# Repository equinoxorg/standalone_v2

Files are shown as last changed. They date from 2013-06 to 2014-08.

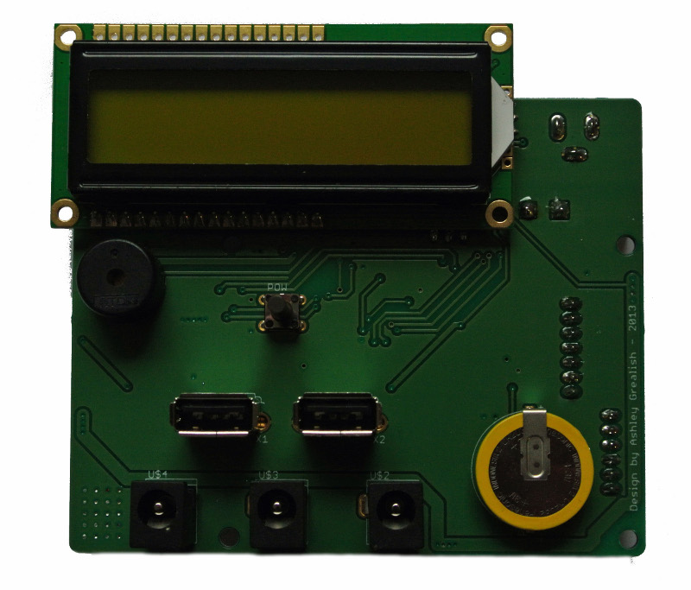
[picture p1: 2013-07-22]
Media/img_front.jpg

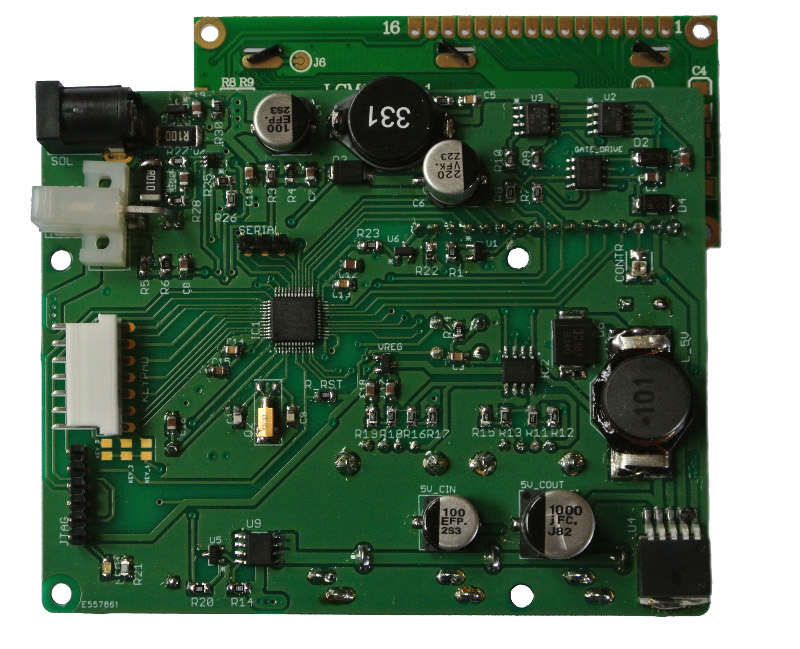
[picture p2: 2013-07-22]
Media/img_back.jpg

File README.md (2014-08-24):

#Standalone 2013 Designs

##Contents

* Hardware: The PCB designs for Pro and Home units
* Software: The source code of the embedded software
* Mechanical: The designs for the faceplate and physical casing
* Media: Any images or other media

Prototype Front

Prototype Back

##Hardware
This project includes hardware schematics and board layouts for Version 2 of the Standalone Battery Box (izuba.box) for e.quinox (www.e.quinox.org).

Cadsoft EAGLE v6 was the tool of choice when designing PCBs.

##Software

This project includes the ARM-based microcontroller software for Version 2 of the Standalone Battery Box (izuba.box) for e.quinox (www.e.quinox.org).

The project uses the Lite version of the Keil µVision IDE.

###Notes
Some code has been deliberately excluded as it would allow misuse of the payment system. If this is a problem please contact [info@e.quinox.org](mailto:info@e.quinox.org).

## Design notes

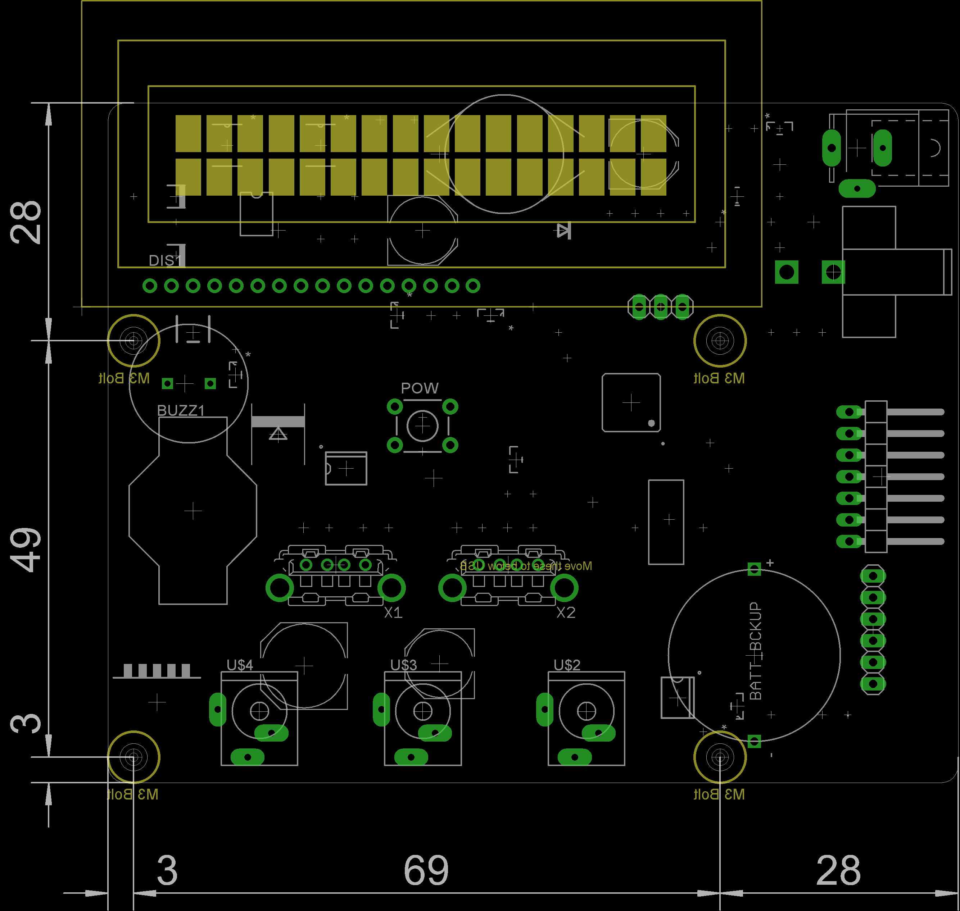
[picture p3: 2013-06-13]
Hardware/standalone/dimensions.png

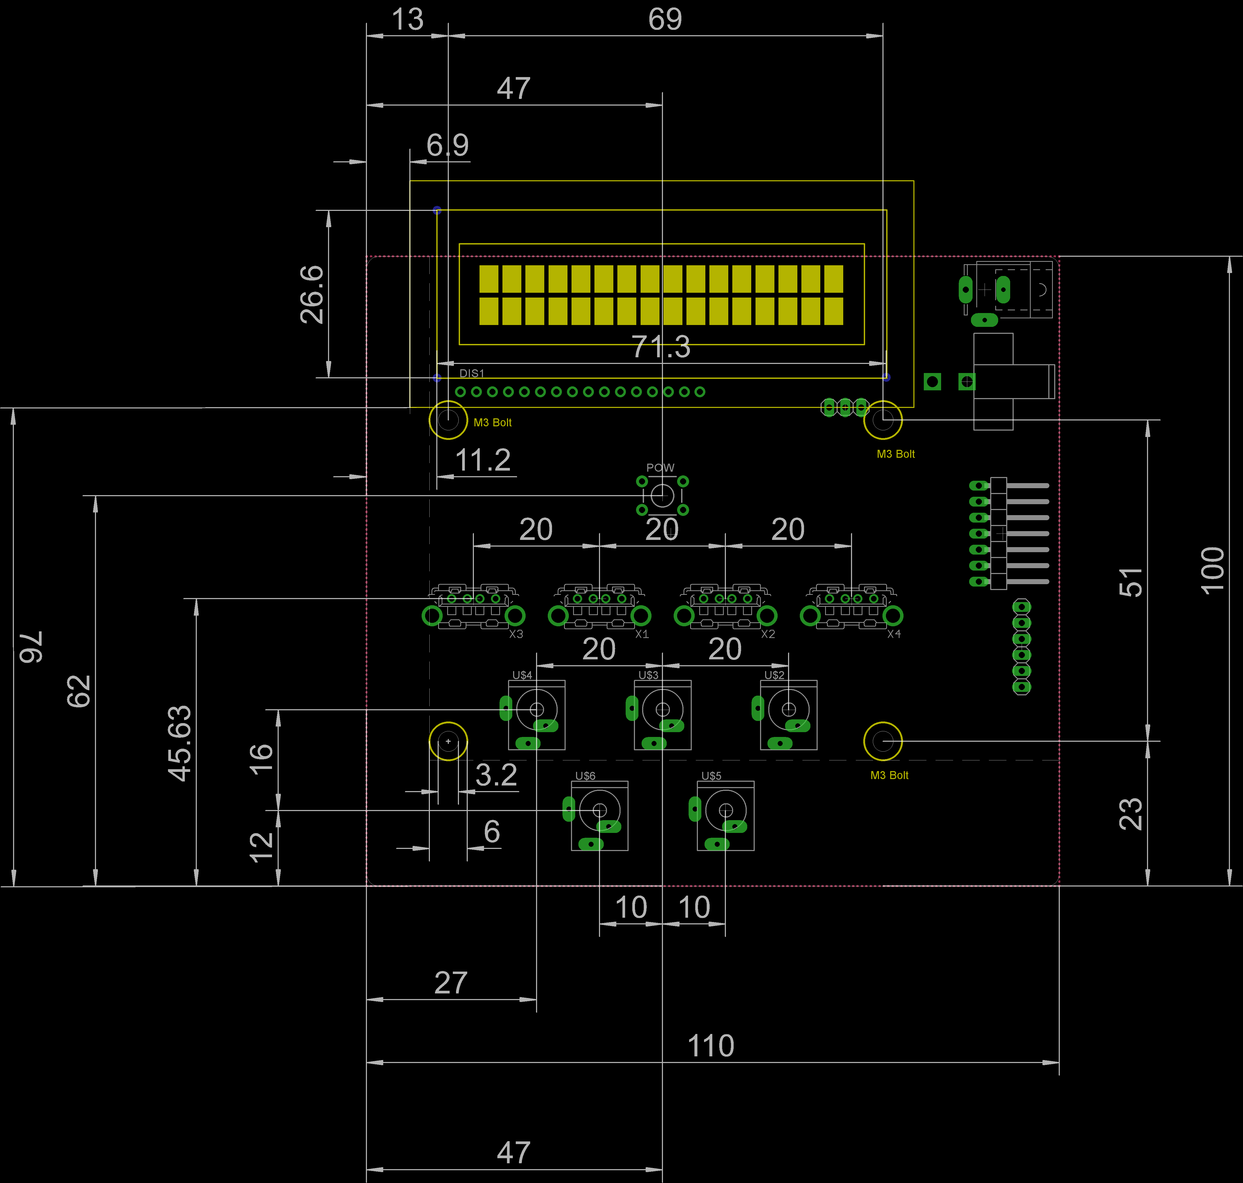
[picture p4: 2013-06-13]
Hardware/standalone_pro/Dimensions.png

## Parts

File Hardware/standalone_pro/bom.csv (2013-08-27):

Qty | Value | Device | Package | Parts | Description | FARNELL | MF | MPN | OC_FARNELL | OC_MOUSER | OC_NEWARK | PACKAGE | RS | SUPPLIER | TOBY
1 |  | BC847B-NPN-SOT23-BEC | SOT23-BEC | T1 | NPN Transistror
1 |  | JACK-PLUG0 | SPC4077 | SOL | DC POWER JACK |  |  |  | unknown |  | unknown |  |  |  | DC-001-A-2.1mm-R
1 |  | PINHD-1X3 | 1X03 | SERIAL | PIN HEADER
1 |  | PINHD-1X6 | 1X06 | JTAG | PIN HEADER
1 |  | PINHD-1X7/90 | 1X07/90 | KEYPAD | PIN HEADER |  |  |  | 588763
1 |  | TAC_SWITCHPTH | TACTILE-PTH | POW | Momentary Switch |  |  |  |  |  |  |  | 758-1979
1 | 0.01 | R-EU_R2512 | R2512 | RS_B | RESISTOR, European symbol
1 | 0.1 | R-EU_R2512 | R2512 | RS_S | RESISTOR, European symbol
1 | 0R | R-EU_M0805 | M0805 | R19 | RESISTOR, European symbol
2 | 1.33k | R-EU_M0805 | M0805 | R5, R14 | RESISTOR, European symbol
2 | 10 | R-EU_M0805 | M0805 | R17, R18 | RESISTOR, European symbol
1 | 100 | R-EU_M0805 | M0805 | R12 | RESISTOR, European symbol
1 | 1000uF | CPOL-EUG | PANASONIC_G | C22 | POLARIZED CAPACITOR, European symbol |  |  |  | 1244342
1 | 100K | R-EU_M0805 | M0805 | R_RST | RESISTOR, European symbol
5 | 100nF | C-EUC0805K | C0805K | C2, C11, C15, C16, C18 | CAPACITOR, European symbol
2 | 100uF | CPOL-EUE | PANASONIC_E | C8, C19 | POLARIZED CAPACITOR, European symbol |  |  |  | 1539489
1 | 100uH | INDUC_BOURNES_SDR2207 | INDUC_BOURNS_SDR2207 | L_5V |  | 1612709 |  |  | 1612709
4 | 10K | R-EU_M0805 | M0805 | R4, R13, R15, R16 | RESISTOR, European symbol
1 | 10K | R_TRIMM_TC33X | R_TRIMM_RC33X | CONTR |  |  |  |  | 1689863 | 652-TC33X-2-103E
1 | 10M | R-EU_M0805 | M0805 | R3 | RESISTOR, European symbol
3 | 10uF | C-EUC0805K | C0805K | C3, C13, C17 | CAPACITOR, European symbol
5 | 1k | R-EU_M0805 | M0805 | R2, R10, R20, R21, R22 | RESISTOR, European symbol
1 | 1k65 | R-EU_M0805 | M0805 | R1 | RESISTOR, European symbol
8 | 1uF | C-EUC0805K | C0805K | C1, C4, C5, C9, C10, C14, C20, C21 | CAPACITOR, European symbol
3 | 200 | R-EU_M0805 | M0805 | R6, R7, R11 | RESISTOR, European symbol
1 | 220uF | CPOL-EUF | PANASONIC_F | C12 | POLARIZED CAPACITOR, European symbol |  |  |  | 9695877
1 | 32.768kHz | MC-306 | MC-306 | Q1 | kHz RANGE CRYSTAL UNIT SMD |  |  | MC-306 | 1712823 |  | -
1 | 330u | INDUC_MURATA_1433428C | INDUC_MURATA_1433428C | L_MPPT |  |  |  |  | 1077018
8 | 49.9k | R-EU_M0805 | M0805 | R24, R26, R28, R30, R32, R34, R36, R38 | RESISTOR, European symbol
2 | 5 | R-EU_M0805 | M0805 | R8, R9 | RESISTOR, European symbol
2 | 6.8pF | C-EUC0603K | C0603K | C6, C7 | CAPACITOR, European symbol |  |  |  | 1856141
8 | 75k | R-EU_M0805 | M0805 | R23, R25, R27, R29, R31, R33, R35, R37 | RESISTOR, European symbol
2 | AP1212 | AP1212 | SO8 | IC3, IC4 | Datasheet: http://www.farnell.com/datasheets/608767.pdf |  |  |  | 1825302
1 | B340-13-F | DIODE_B340-13-F | SMC | D6 |  |  |  |  | 1843695
1 | BUZZ_14MM | BUZZ_14MM | BUZZ_14MM_5M_PINS | BUZZ1 |  |  |  |  | 1192513
1 | BZX384-C3V6 | BZX384-C3V6 | SOD323 | D1 |  |  |  |  | 8735654
2 | CON_MOLEX_39_29_1028 | CON_MOLEX_39_29_1028 | MOLEX_39_29_1028 | BATT, INVERTER |  |  |  |  | 1012166
1 | EQUINOX_LOGO_LARGE | EQUINOX_LOGO_LARGE | EQUINOX_LOGO_LARGE | U$1
2 | FDS6690a | DMS3016SSS-13 | SOIC127P600X175-8N | U4, U5 | ENHANCEMENT MODE MOSFET |  |  |  | 9845275 |  |  | SOIC-8
1 | INA213AIDCKT | INA213AIDCKT | SOT65P210X110-6N | U7 | CURRENT SHUNT MONITOR |  |  | INA213AIDCKT | 1754261 |  | 05N1040 | SC-70-6 |  | Texas Instruments
1 | IR2104S | IR2104S | IR2104S | IC1 | Half Bridge Mosfet - IGBT driver SOIC |  |  |  | 8638756
4 | KUSBVX | KUSBVX | KUSBVX | X1, X2, X3, X4 | Vertical,Top Entry Universal Serial Bus Connector KUSBVX Series
5 | KYCON_KLDVX-0202 | KYCON_KLDVX-0202 | KYCON_KLVDX_2020_B | DC1, DC2, DC3, DC4, DC5 |  |  |  |  |  |  |  |  |  |  | DC-031-B
1 | LCD_16X2_R2 | LCD_16X2_R2 | LCD_16X2_R2 | DIS1 | Supplier: info |  |  |  | unknown |  | unknown
1 | LM2576S | LM2576S | TO263-5 | U9 |  |  |  |  | 1469178
1 | MCP1700T-3302E/TT | MCP1700T-3302E/TT | SOT95P237X112-3N | VREG | Low Quiescent Current LDO |  |  | MCP1700T-3302E/TT | 1296592 |  | 88H9817 | SOT23-3 |  | Microchip
4 | NMOS_2N7002 | NMOS_2N7002 | SOT103P240X110-3N | U2, U3, U6, U10 | N-CHANNEL ENHANCEMENT MODE FIELD EFFECT TRANSISTOR |  |  | 2N7002-7-F | 1713823 |  | 25R5679 | SOT-23-3 |  | DIODES INC.
1 | POW_3V3 | LEDCHIPLED_0805 | CHIPLED_0805 | LED1 | LED
1 | RELAY_G5RL-1E | RELAY_G5RL-1E | G5RL-1E | U$2
1 | RENATA_COIN_CELL | PANASONIC_CR2032_1298246 | PANASONIC_CR2032_1298246 | BATT_BCKUP | Farnell Part No: 1298246 |  |  |  | 1298246
1 | S1A-E3/5AT | DIODE-DO-214AC | DO-214AC | D2 | DIODE |  |  |  | 9550216
2 | SSB43L | DIODE_SSB43L | DO214AA | D4, D5 | VISHAY - SSB43L-E3/52T - DIODE, SCHOTTKY, 4A, 30V |  |  |  | 1336556
1 | STM32F050C6T6A | STM32F050C6T6A | LQFP48 | IC2 |  |  |  |  | 2115059
2 | US1D | DIODE-DO-214AC | DO-214AC | D3, D7 | DIODE |  |  |  | 1625280
1 | ZXCT1107SA-7 | ZXCT1107SA-7 | SOT91P240X110-3N | U1 | LOW POWER HIGH-SIDE CURRENT MONITORS |  |  | ZXCT1107SA-7 | 1904027 |  | 55T4047 | SOT-23-3 |  | DIODES INC.

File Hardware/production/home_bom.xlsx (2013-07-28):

e.quinox izuba.box Home Bill Of Materials
Date | 2013-07-17
Qty | Populate | Reference Designator | Pins | SMT? | IC? | SMT Pads | IC Pads | TH Pads | Item Description | Column1 | Column2 | Supplier | Supplier Part No | Manufacturer | Manufacturer Part No | Notes | Unit Price | Order Quantity | Ordered | Total Cost
1 | Y | BATT | 2 | N | N | 0 | 0 | 2 | CON_MOLEX_39_29_1028 | MOLEX_39_29_1028 |  | FARNELL | 1012166 | Molex | 39-29-1028 |  | £0.41 | 83 | 83 | £34.03
1 | Y | BATT_BCKUP | 2 | N | N | 0 | 0 | 2 | RENATA_COIN_CELL | PANASONIC_CR2032_1298246 | Farnell Part No: 1298246 | FARNELL | 1298246 | PANASONIC | CR-2032/HFN |  | £1.02 | 83 | 83 | £84.66
1 | Y | BUZZ1 | 2 | N | N | 0 | 0 | 2 | BUZZ_14MM | BUZZ_14MM_5M_PINS |  | FARNELL | 1192513 | Murata | PKM13EPYH4000-A0 |  | £0.27 | 83 | 83 | £22.41
2 | Y | C1, C9 | 2 | Y | N | 4 | 0 | 0 | 6.8pF | C0603K | CAPACITOR | FARNELL | 1856141 | Multicomp | MCCA000982 |  | £0.02 | 165 | 200 | £3.40
8 | Y | C2, C10, C11, C12, C16, C17, C18, C19 | 2 | Y | N | 16 | 0 | 0 | 1uF | C0805K | CAPACITOR | Quick-Tech | QCC-00106 | Samsung | CL21B105KAFNNNE |  |  | 660 |  | £0.00
1 | Y | C22 | 2 | Y | N | 2 | 0 | 0 | 1000uF | PANASONIC_G | POLARIZED CAPACITOR | FARNELL | 1244342 | PANASONIC | EEEFC0J102AP |  | £0.25 | 83 | 100 | £25.00
5 | Y | C3, C5, C13, C14, C15 | 2 | Y | N | 10 | 0 | 0 | 100nF | C0805K | CAPACITOR | Quick-Tech | QCC-00154 | Samsung | CL21B104KCC5PNC |  |  | 413 |  | £0.00
2 | Y | C4, C21 | 2 | Y | N | 4 | 0 | 0 | 100uF | PANASONIC_E | POLARIZED CAPACITOR | FARNELL | 1539489 | PANASONIC | EEEFP1E101AP |  | £0.21 | 165 | 170 | £35.70
1 | Y | C6 | 2 | Y | N | 2 | 0 | 0 | 220uF | PANASONIC_F | POLARIZED CAPACITOR | FARNELL | 9695877 | PANASONIC | EEEFK1V221P |  | £0.20 | 83 | 100 | £20.00
3 | Y | C7, C8, C20 | 2 | Y | N | 6 | 0 | 0 | 10uF | C0805K | CAPACITOR | Quick-Tech | QCC-00108 | Samsung | CL21A106KOFNNNE |  |  | 248 |  | £0.00
1 | Y | CONTR | 3 | Y | N | 3 | 0 | 0 | 10K | R_TRIMM_RC33X |  | FARNELL | 1689863 | Bourns | TC33X-2-103E |  | £0.21 | 83 | 83 | £17.43
2 | Y | D1, D3 | 2 | Y | N | 4 | 0 | 0 | SSB43L | DO214AA | VISHAY - SSB43L-E3/52T - DIODE, SCHOTTKY, 4A, 30V | FARNELL | 1336556 | Vishay | SSB43L-E3/52T |  | £0.29 | 165 | 165 | £47.85
1 | Y | D2 | 2 | Y | N | 2 | 0 | 0 | S1A-E3/5AT | DO-214AC | DIODE | FARNELL | 9550216 | Vishay | S1A-E3/5AT |  | £0.09 | 83 | 83 | £7.64
1 | Y | D4 | 2 | Y | N | 2 | 0 | 0 | US1D | DO-214AC | DIODE | FARNELL | 1625280 | Multicomp | US1D |  | £0.09 | 83 | 85 | £7.65
1 | Y | D5 | 2 | Y | N | 2 | 0 | 0 | BZX384-C3V6 | SOD323 |  | FARNELL | 8735654 | NXP | BZX384-C3V6 |  | £0.03 | 83 | 90 | £2.52
1 | Y | D6 | 2 | Y | N | 2 | 0 | 0 | B340-13-F | SMC |  | FARNELL | 1843695 | Diodes inc. | B340-13-F |  | £0.17 | 83 | 83 | £13.70
3 | Y | DC1, DC2, DC3 | 3 | N | N | 0 | 0 | 9 | KYCON_KLDVX-0202 | KYCON_KLVDX_2020_B |  | TOBY | DC-031-B | TOBY | DC-031-B | Shipped with Matt Douthwaite order | £0.25 | 248 | 248 | £62.00
1 | Y | DIS1 | 16 | N | N | 0 | 0 | 16 | LCD_16X2_R2 | LCD_16X2_R2 | Supplier: info | Quick-Tech | QCJ-00018 | Nextron | R-211-1611-0021-001 | Only pin header soldered, LCD will be attached by e.quinox |  | 83 |  | £0.00
1 | Y | IC1 | 48 | Y | Y | 0 | 48 | 0 | STM32F050C6T6A | LQFP48 |  | FARNELL | 2115059 | STMicroelectronics | STM32F050C6T6A | Purchased from Mouser: 511-STM32F050C6T6A | £2.01 | 83 | 83 | £166.83
1 | Y | IC2 | 8 | Y | Y | 0 | 8 | 0 | AP1212 | SO8 | Datasheet: http://www.farnell.com/datasheets/608767.pdf | FARNELL | 1825302 | Diodes inc. | AP1212HSG-13 |  | £0.56 | 83 | 83 | £46.48
1 | Y | IC3 | 8 | Y | Y | 0 | 8 | 0 | IR2104S | IR2104S | Half Bridge Mosfet - IGBT driver SOIC | FARNELL | 8638756 | International Rectifier | IR2104SPBF |  | £0.71 | 83 | 100 | £71.00
1 | Y | JTAG | 6 | N | N | 0 | 0 | 6 |  | 1X06 | PIN HEADER | Quick-Tech | QCJ-00012 | Nextron | R-211-0611-0021-001 |  |  | 83 |  | £0.00
1 | Y | KEYPAD | 7 | N | N | 0 | 0 | 7 |  | 1X07/90 | PIN HEADER | FARNELL | 588763 | TE CONNECTIVITY | 640457-7 |  | £0.21 | 83 | 85 | £17.85
1 | Y | L_5V | 2 | Y | N | 2 | 0 | 0 | 100uH | INDUC_BOURNS_SDR2207 |  | FARNELL | 1612709 | Bourns | SDR2207-101KL |  | £0.59 | 83 | 83 | £48.97
1 | Y | L_MPPT | 2 | Y | N | 2 | 0 | 0 | 330u | INDUC_BOURNS_SDR1806 | Datasheet: http://www.bourns.com/data/global/pdfs/SDR1806.pdf | FARNELL | 1929706 | Bourns | SDR1806-331KL |  | £0.64 | 83 | 83 | £53.12
1 | N | LED1 | 2 | Y | N | 0 | 0 | 0 | POW_3V3 | CHIPLED_0805 | LED |  |  |  |  | Do not populate |  | 83 |  | £0.00
1 | Y | POW | 4 | N | N | 0 | 0 | 4 |  | TACTILE-PTH | Momentary Switch | RS | 758-1979 | ALPS | SKHHDJA010 | Also requires Switch cap. Farnell: 9561552 | £0.20 | 83 | 83 | £16.60
1 | Y | PTC1 | 2 | N | N | 0 | 0 | 2 | 7A | PTC_MF_R700 |  | FARNELL | 9350551 | Bourns | MF-R700 |  | £0.33 | 83 | 100 | £33.00
1 | Y | Q1 | 4 | Y | N | 4 | 0 | 0 | 32.768kHz | MC-306 | kHz RANGE CRYSTAL UNIT SMD | FARNELL | 1712823 | EPSON TOYOCOM | MC-306, 32.768KHZ, 6PF |  | £0.62 | 83 | 83 | £51.46
1 | Y | R1 | 2 | Y | N | 2 | 0 | 0 | 100 | M0805 | RESISTOR | Quick-Tech | QCR-00301 | Yageo | RC0805FR-07100RL |  |  | 83 |  | £0.00
4 | Y | R11, R13, R16, R18 | 2 | Y | N | 8 | 0 | 0 | 75k | M0805 | RESISTOR | Quick-Tech | QCR-00370 | Yageo | RC0805FR-0775KL |  |  | 330 |  | £0.00
4 | Y | R12, R15, R17, R19 | 2 | Y | N | 8 | 0 | 0 | 49.9k | M0805 | RESISTOR | Quick-Tech | QCR-00365 | Yageo | RC0805FR-0747KL | 47k used in place of 49k9 |  | 330 |  | £0.00
2 | Y | R14, R_RST | 2 | Y | N | 4 | 0 | 0 | 100K | M0805 | RESISTOR | Quick-Tech | QCR-00373 | Yageo | RC0805FR-07100KL |  |  | 165 |  | £0.00
3 | Y | R2, R7, R8 | 2 | Y | N | 6 | 0 | 0 | 200 | M0805 | RESISTOR | Quick-Tech | QCR-00308 | Yageo | RC0805FR-07200RL |  |  | 248 |  | £0.00
5 | Y | R20, R21, R23, R24, R29 | 2 | Y | N | 10 | 0 | 0 | 1k | M0805 | RESISTOR | Quick-Tech | QCR-00325 | Yageo | RC0805FR-071KL |  |  | 413 |  | £0.00
1 | Y | R22 | 2 | Y | N | 2 | 0 | 0 | 0R | M0805 | RESISTOR | Quick-Tech | QCR-00268 | Yageo | RC0805JR-070RL |  |  | 83 |  | £0.00
2 | Y | R27, R28 | 2 | Y | N | 4 | 0 | 0 | 10 | M0805 | RESISTOR | Quick-Tech | QCR-00279 | Yageo | RC0805FR-0710RL |  |  | 165 |  | £0.00
4 | Y | R3, R5, R25, R26 | 2 | Y | N | 8 | 0 | 0 | 10K | M0805 | RESISTOR | Quick-Tech | QCR-00349 | Yageo | RC0805FR-0710KL |  |  | 330 |  | £0.00
1 | Y | R30 | 2 | Y | N | 2 | 0 | 0 | 1k65 | M0805 | RESISTOR | Quick-Tech | QCR-00330 | Yageo | RC0805FR-071K6L | 1k6 used in place of 1k65 |  | 83 |  | £0.00
1 | Y | R31 | 2 | Y | N | 2 | 0 | 0 | 10M | M0805 | RESISTOR | Quick-Tech | QCR-00407 | Yageo | RC0805FR-0710ML |  |  | 83 |  | £0.00
2 | Y | R4, R6 | 2 | Y | N | 4 | 0 | 0 | 1.33k | M0805 | RESISTOR | Quick-Tech | QCR-00328 | Yageo | RC0805FR-071K3L | 1k3 used in place of 1k33 |  | 165 |  | £0.00
2 | Y | R9, R10 | 2 | Y | N | 4 | 0 | 0 | 5 | M0805 | RESISTOR | Quick-Tech | QCR-00275 | Yageo | RC0805FR-075R1L | 5r1 used in place of 5r |  | 165 |  | £0.00
1 | Y | RS_B | 2 | Y | N | 2 | 0 | 0 | 0.01 | R2512 | RESISTOR | FARNELL | 2079429 | Welwyn | LRMAP2512-R01FT4 |  | £0.22 | 83 | 85 | £18.70
1 | Y | RS_S | 2 | Y | N | 2 | 0 | 0 | 0.1 | R2512 | RESISTOR | FARNELL | 1865265 | Bourns | CRM2512-FX-R100ELF |  | £0.12 | 83 | 100 | £12.00
1 | Y | SERIAL | 3 | N | N | 0 | 0 | 3 |  | 1X03 | PIN HEADER | Quick-Tech | QCJ-00009 | Nextron | R-211-0311-0021-001 |  |  | 83 |  | £0.00
1 | Y | SOL | 3 | N | N | 0 | 0 | 3 |  | SPC4077 | DC POWER JACK | TOBY | DC-001-A-2.1mm-R | TOBY | DC-001-A-2.1mm-R |  | £0.13 | 83 | 83 | £10.79
1 | Y | T1 | 3 | Y | N | 3 | 0 | 0 |  | SOT23-BEC | BC847B NPN Transistror | FARNELL | 1081232 | NXP | BC847B |  | £0.02 | 83 | 90 | £1.44
1 | Y | U10 | 3 | Y | N | 3 | 0 | 0 | ZXCT1107SA-7 | SOT91P240X110-3N | LOW POWER HIGH-SIDE CURRENT MONITORS | FARNELL | 1904027 | Diodes inc. | ZXCT1107SA-7 |  | £0.34 | 83 | 83 | £28.22
2 | Y | U2, U3 | 8 | Y | Y | 0 | 16 | 0 | FDS6690a | SOIC127P600X175-8N | ENHANCEMENT MODE MOSFET | FARNELL | 9845275 | FAIRCHILD SEMICONDUCTOR | FDS6690A |  | £0.42 | 165 | 165 | £69.30
1 | Y | U4 | 6 | Y | N | 6 | 0 | 0 | LM2576S | TO263-5 |  | FARNELL | 1469178 | Texas Instruments | LM2576S-5.0/NOPB |  | £1.50 | 83 | 100 | £150.00
4 | Y | U5, U8, U11, U12 | 3 | Y | N | 12 | 0 | 0 | NMOS_2N7002 | SOT103P240X110-3N | N-CHANNEL ENHANCEMENT MODE FIELD EFFECT TRANSISTOR | FARNELL | 1713823 | DIODES INC. | 2N7002-7-F |  | £0.04 | 330 | 330 | £12.87
1 | Y | U7 | 6 | Y | Y | 0 | 6 | 0 | INA213AIDCKT | SOT65P210X110-6N | CURRENT SHUNT MONITOR | FARNELL | 1754261 | Texas Instruments | INA213AIDCKT |  | £0.69 | 83 | 100 | £69.00
1 | Y | U9 | 8 | Y | Y | 0 | 8 | 0 | RSS090P03 | SO8 |  | FARNELL | 1858950 | Vishay | SI4431CDY-T1-GE3 | Used in place of RSS090P03FU6TB (1525544) | £0.41 | 83 | 83 | £34.03
1 | Y | VREG | 3 | Y | N | 3 | 0 | 0 | MCP1700T-3302E/TT | SOT95P237X112-3N | Low Quiescent Current LDO | FARNELL | 1296592 | Microchip | MCP1700T-3302E/TT |  | £0.24 | 83 | 83 | £19.92
2 | Y | X1, X2 | 6 | N | N | 0 | 0 | 12 | KUSBVX | KUSBVX | Vertical,Top Entry Universal Serial Bus Connector KUSBVX Series | FARNELL | 2112372 | MULTICOMP | USB-A-S-VT |  | £0.17 | 165 | 170 | £29.07
 |  |  |  |  |  |  |  |  |  |  |  |  |  |  |  |  |  |  | Total | £1344.63
BOM Lines |  | 54 |  |  |  |  |  |  |  |  |  |  |  |  |  |  |  |  | Per Unit | £17.93
Total Components |  | 96
SMT Pads |  | 162
IC SMT Pads |  | 94
TH Pads |  | 68
Quantity |  | 75
Safety |  | 10%

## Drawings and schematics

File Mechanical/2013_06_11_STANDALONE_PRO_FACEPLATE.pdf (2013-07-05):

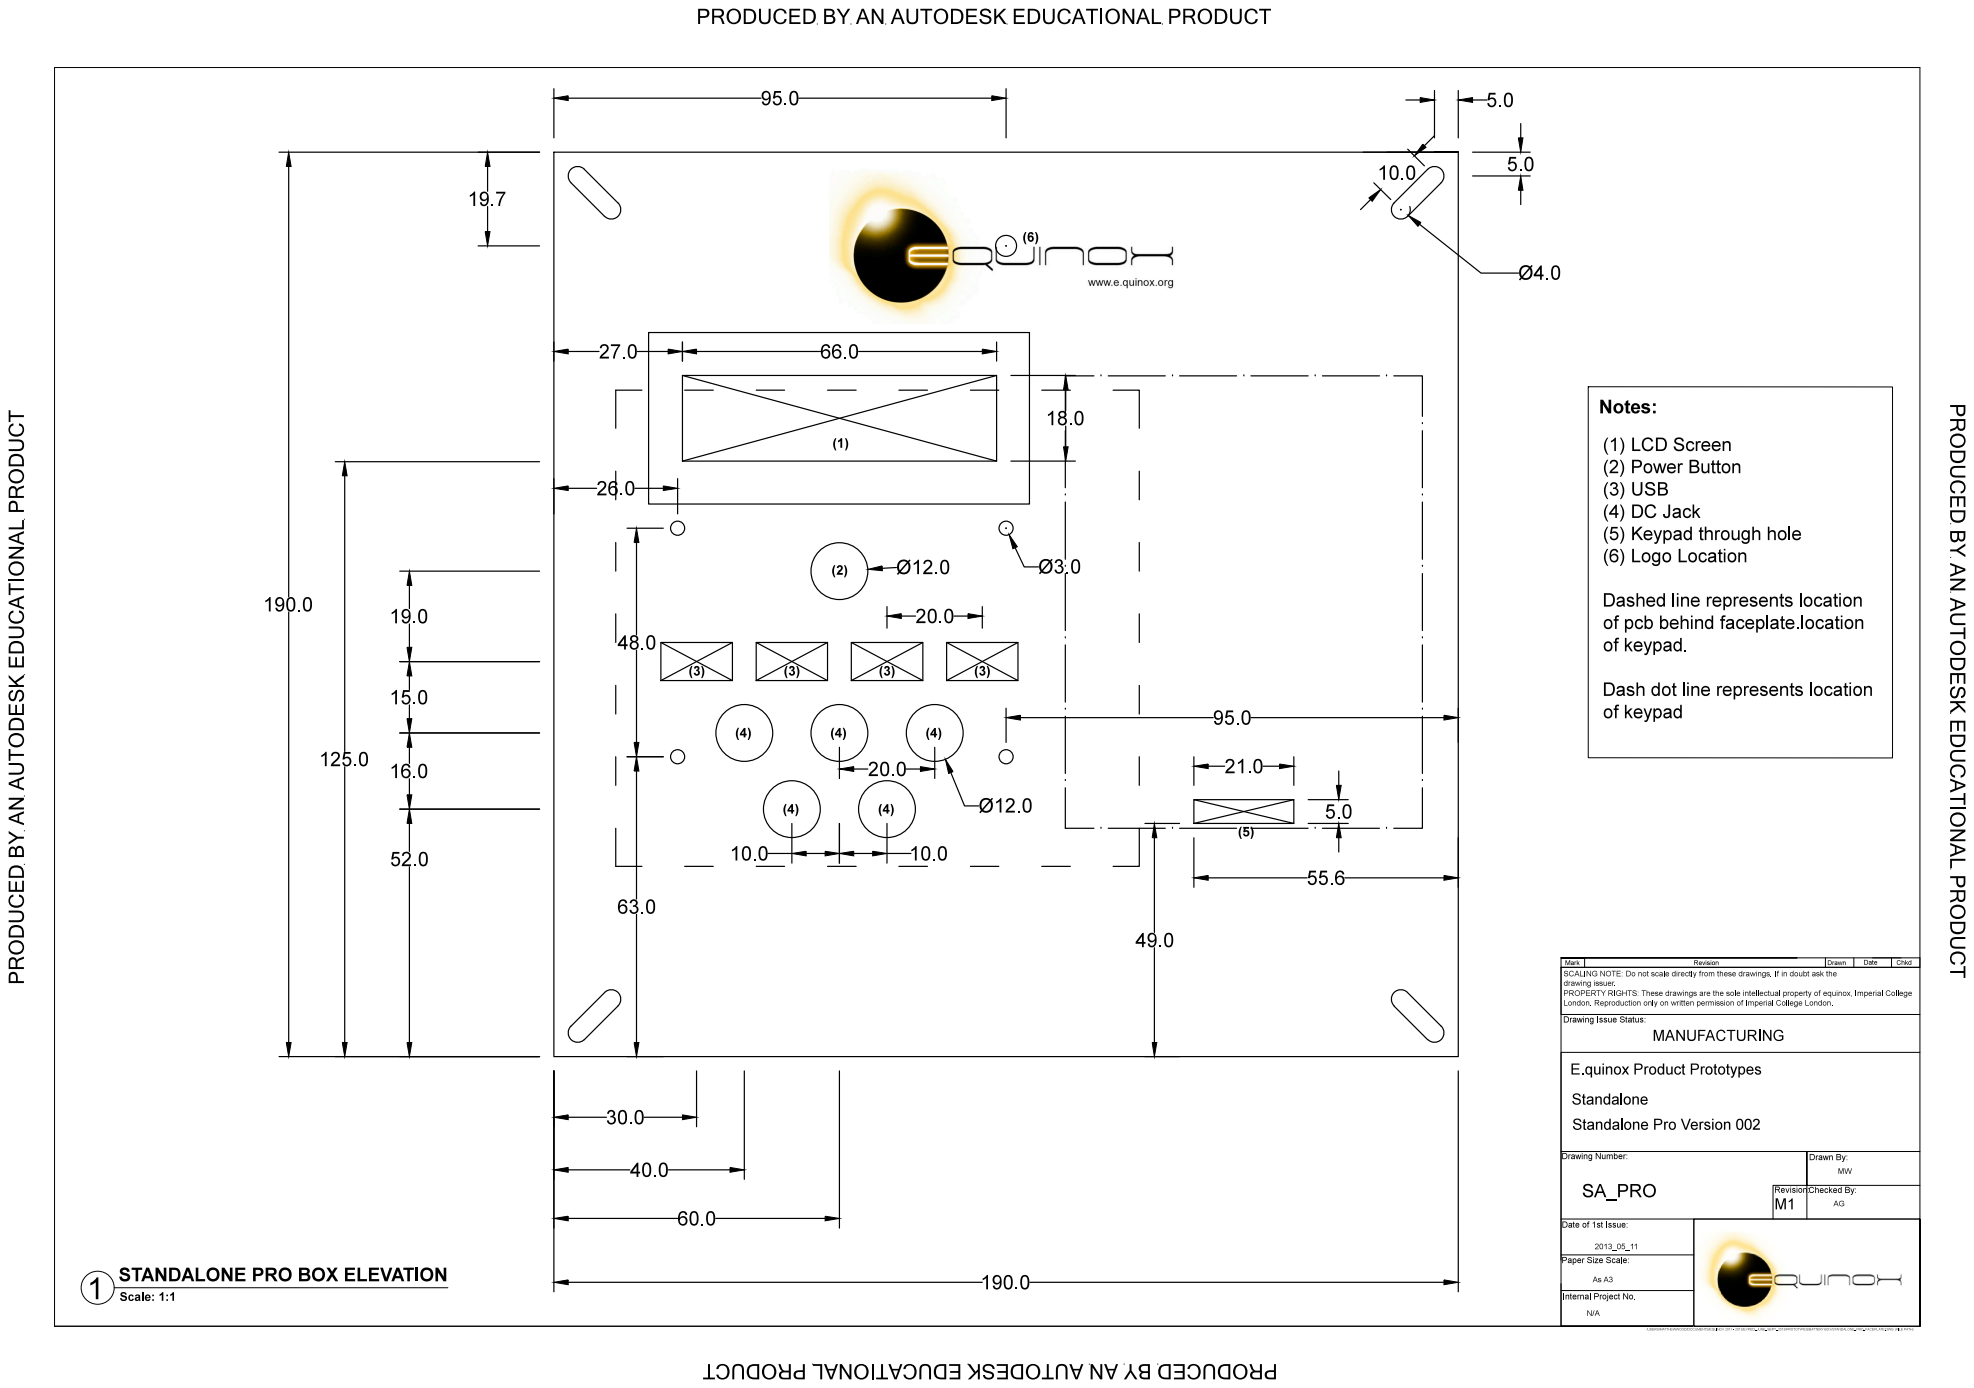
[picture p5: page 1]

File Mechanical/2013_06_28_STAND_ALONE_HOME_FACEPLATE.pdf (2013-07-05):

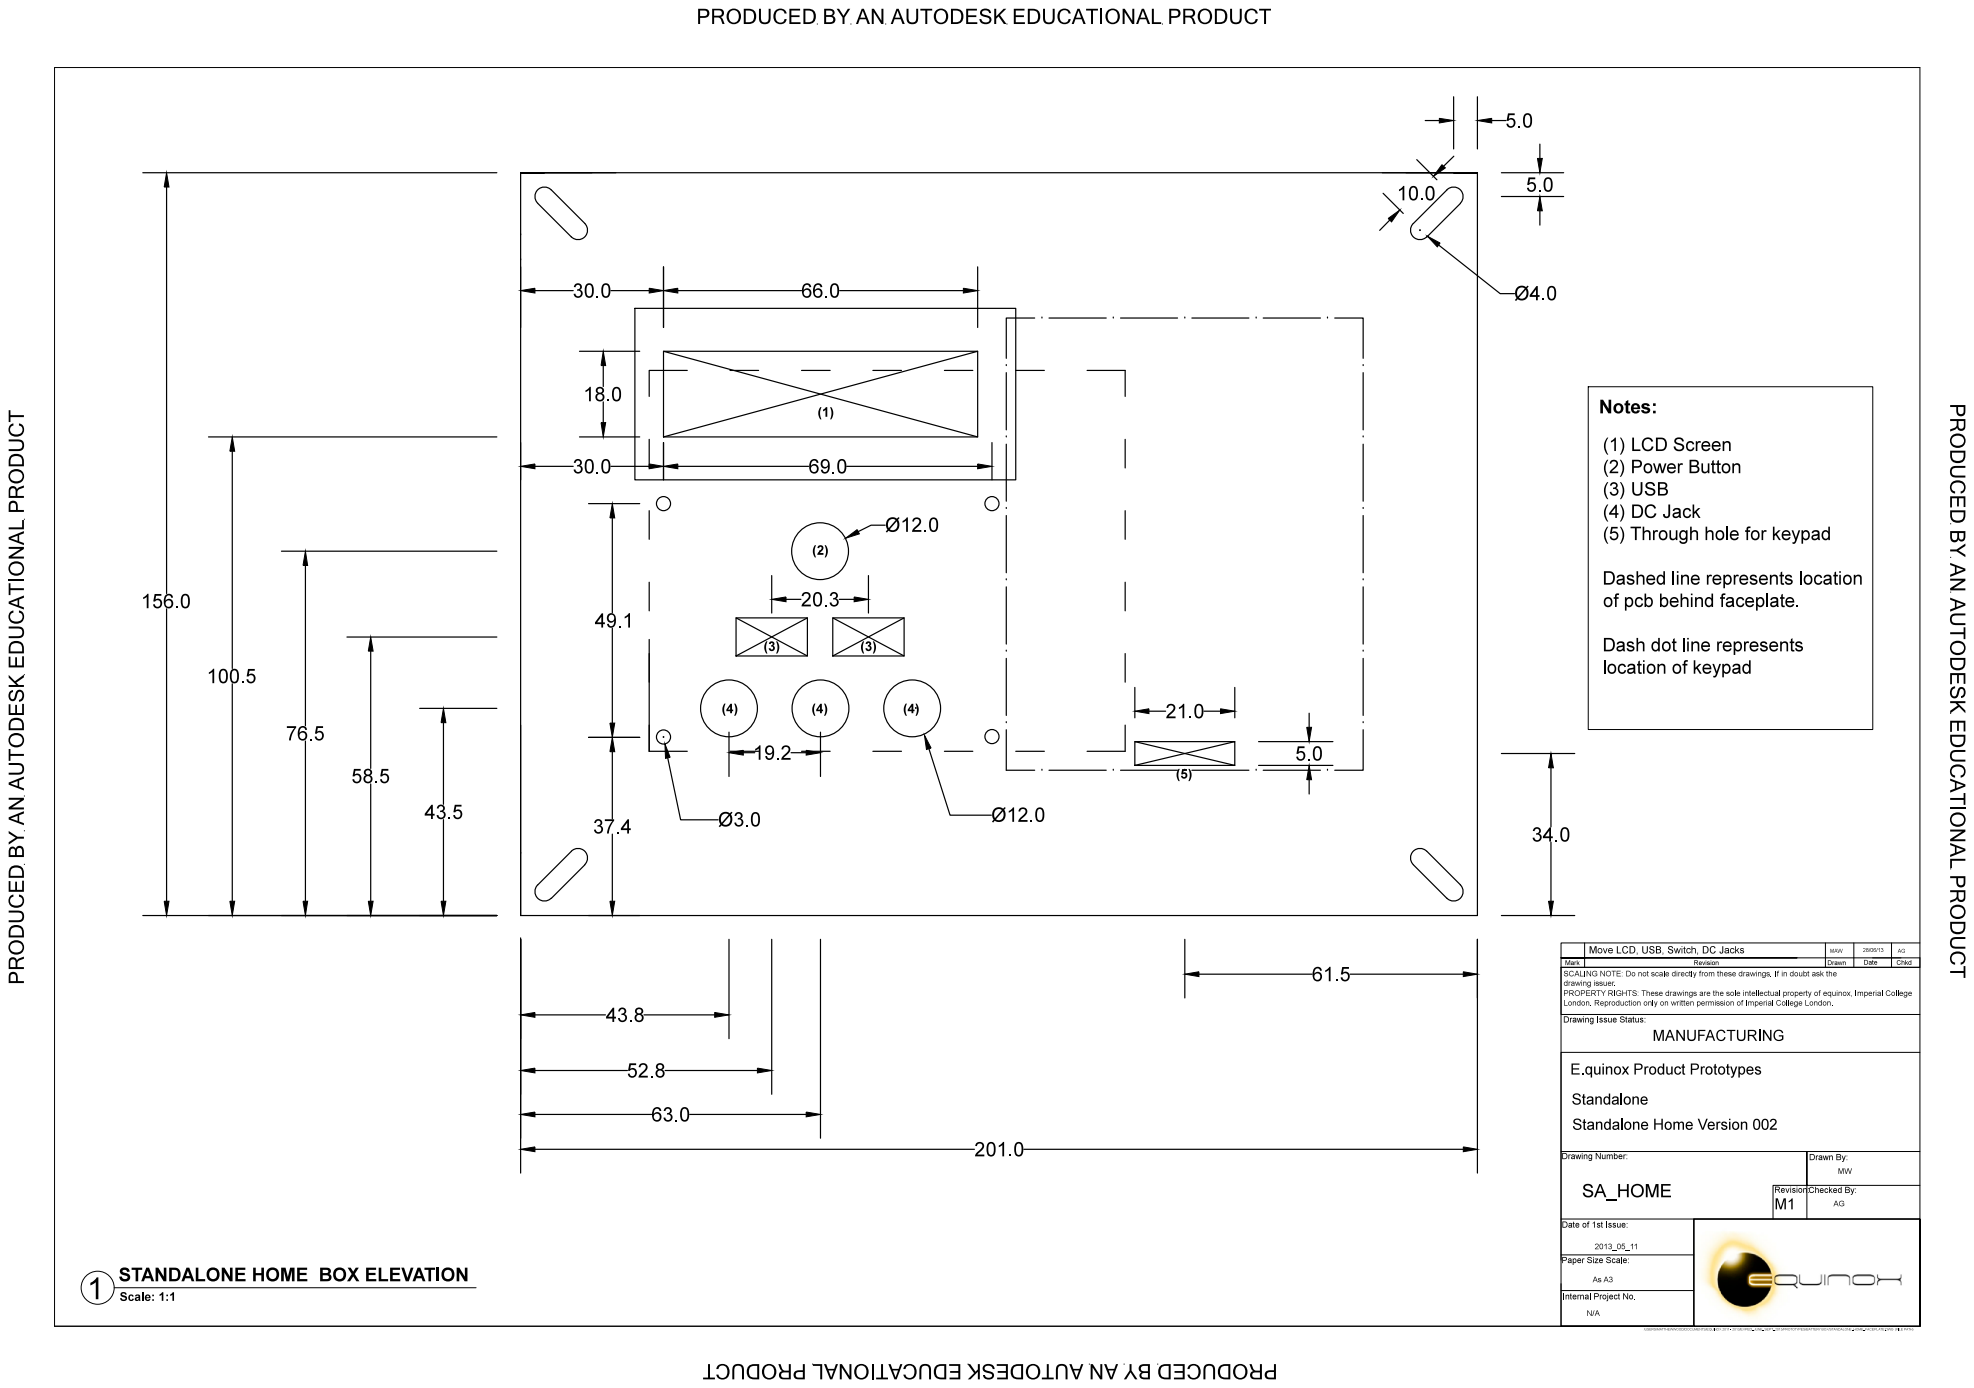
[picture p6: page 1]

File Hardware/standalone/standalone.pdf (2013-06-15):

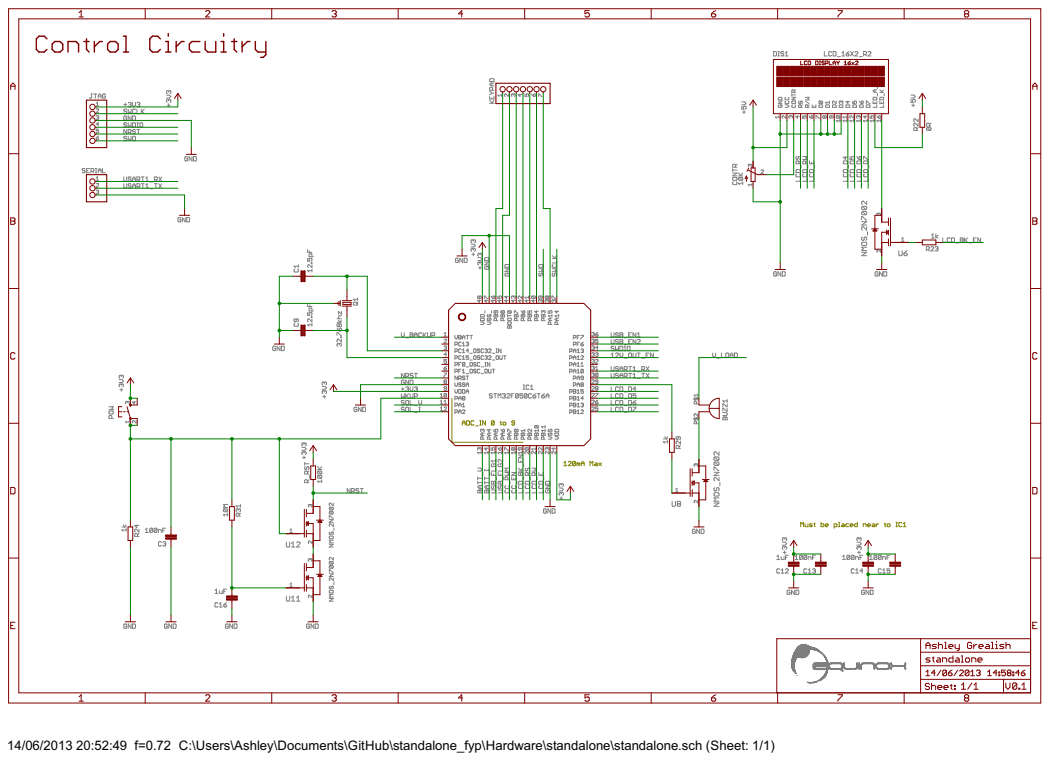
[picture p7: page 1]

14/06/2013 20:52:49 f=0.72 C:\Users\Ashley\Documents\GitHub\standalone_fyp\Hardware\standalone\standalone.sch (Sheet: 1/1)

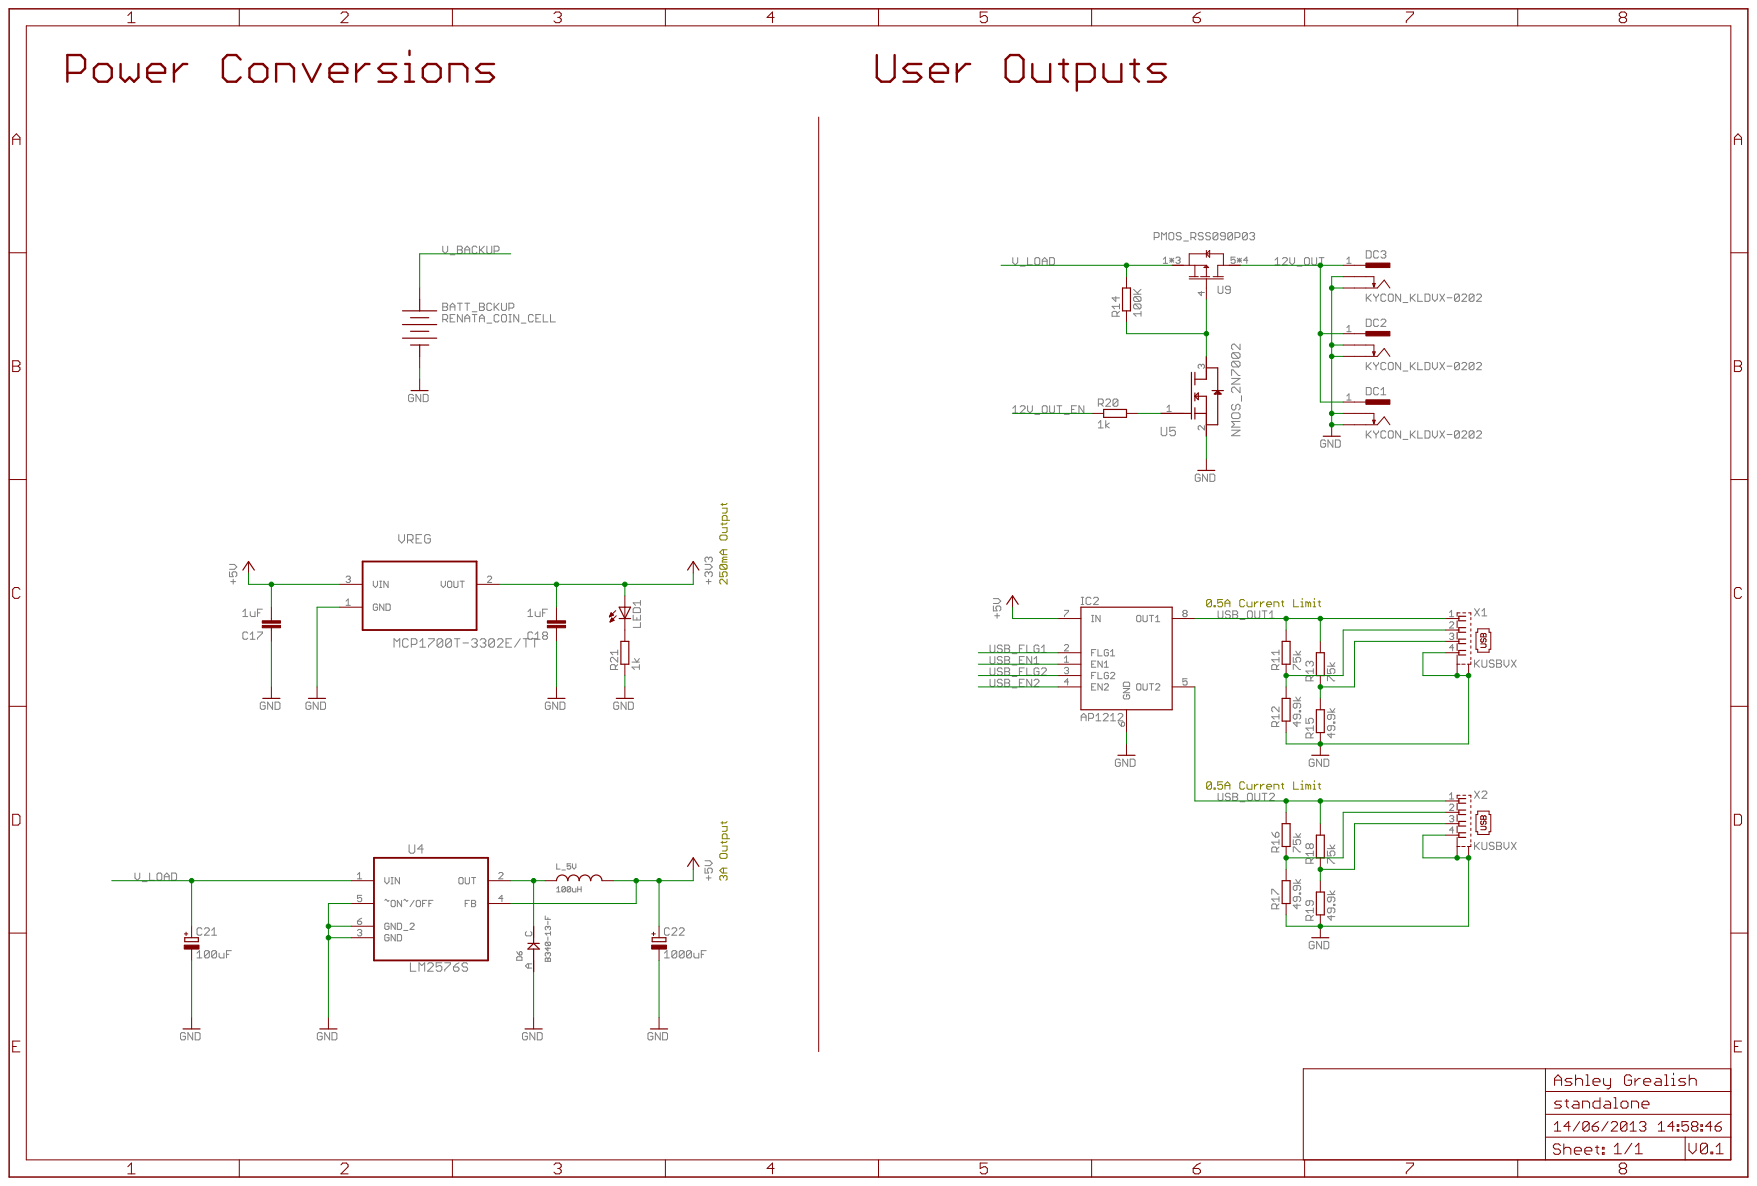
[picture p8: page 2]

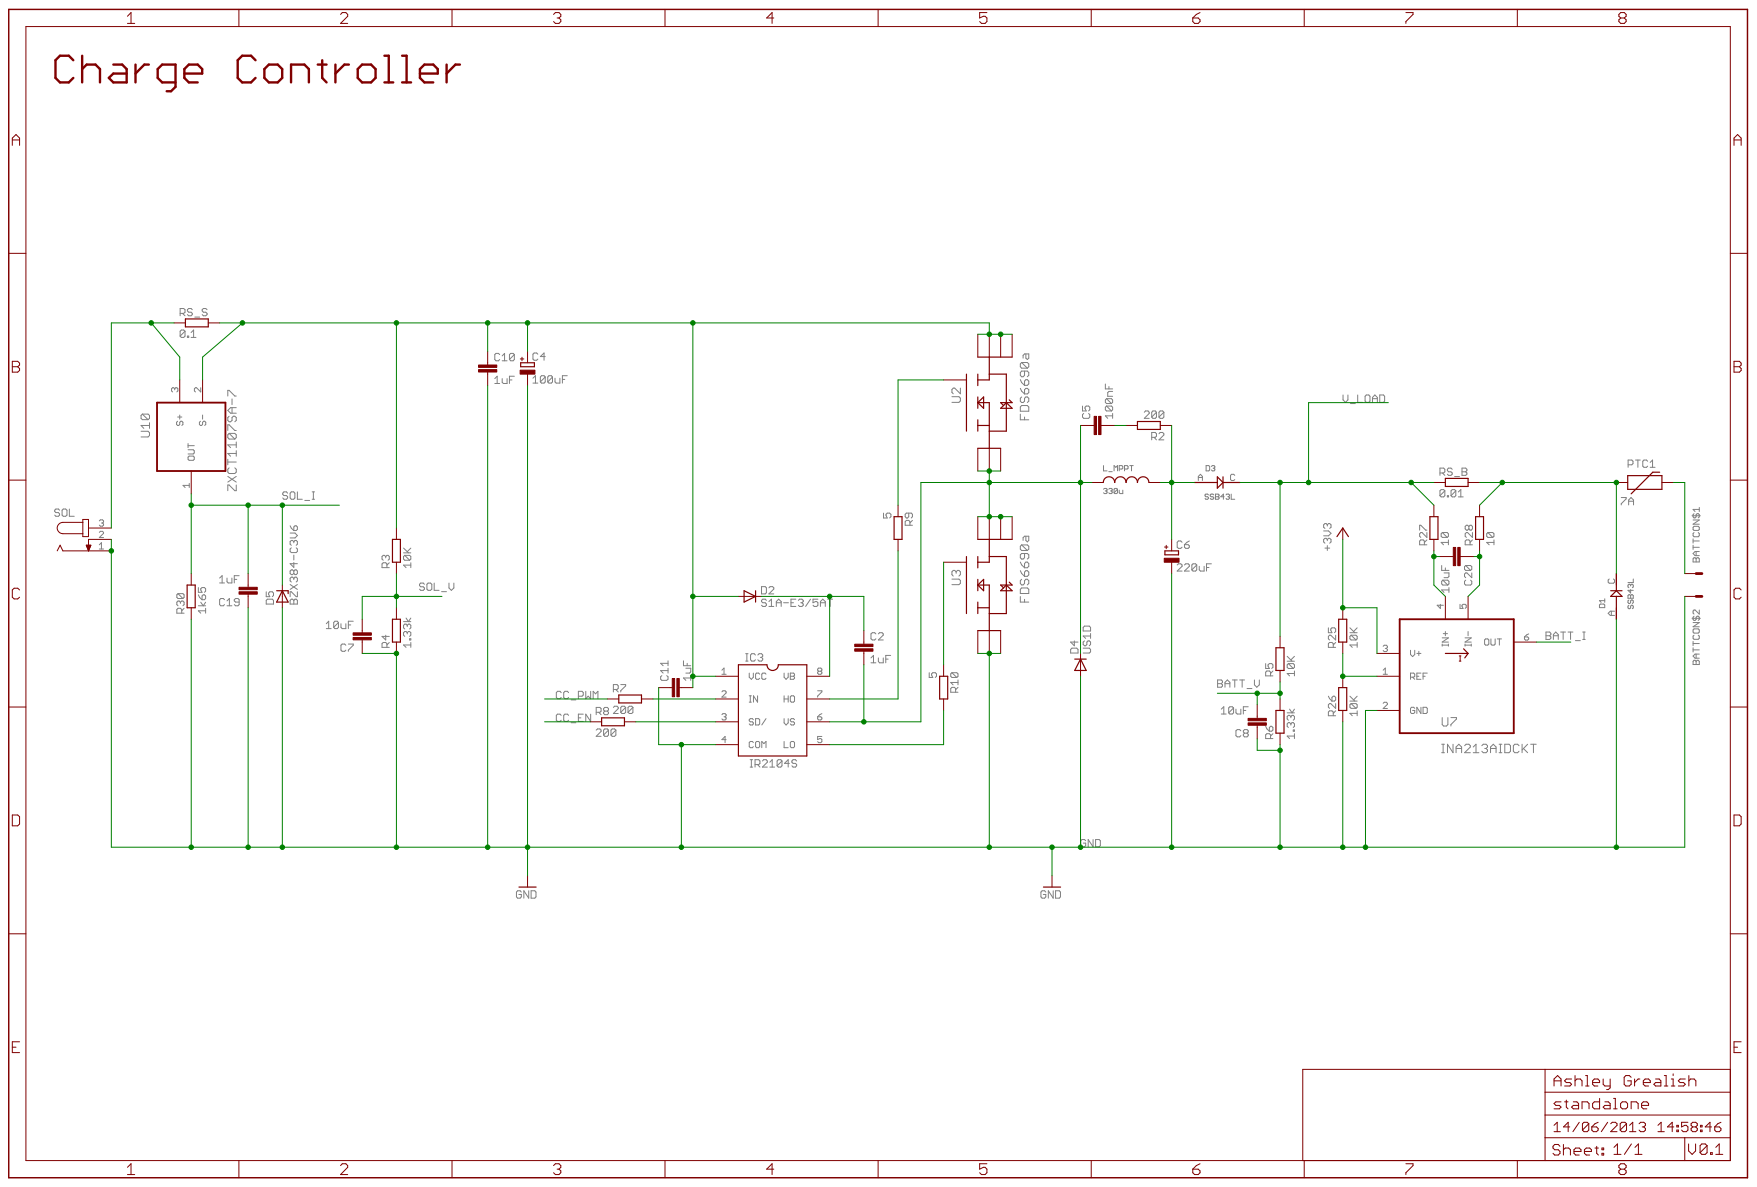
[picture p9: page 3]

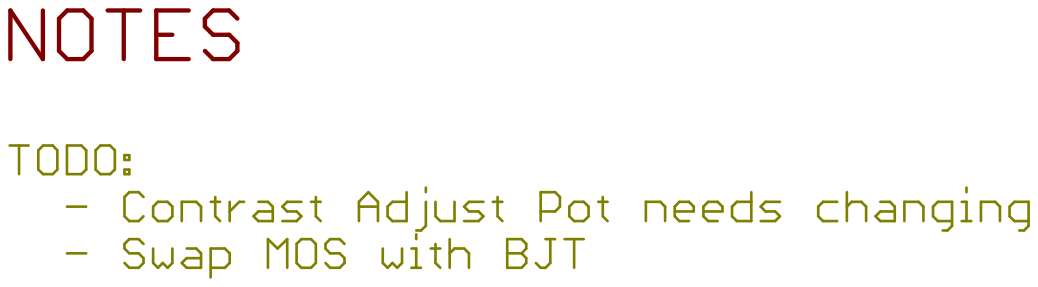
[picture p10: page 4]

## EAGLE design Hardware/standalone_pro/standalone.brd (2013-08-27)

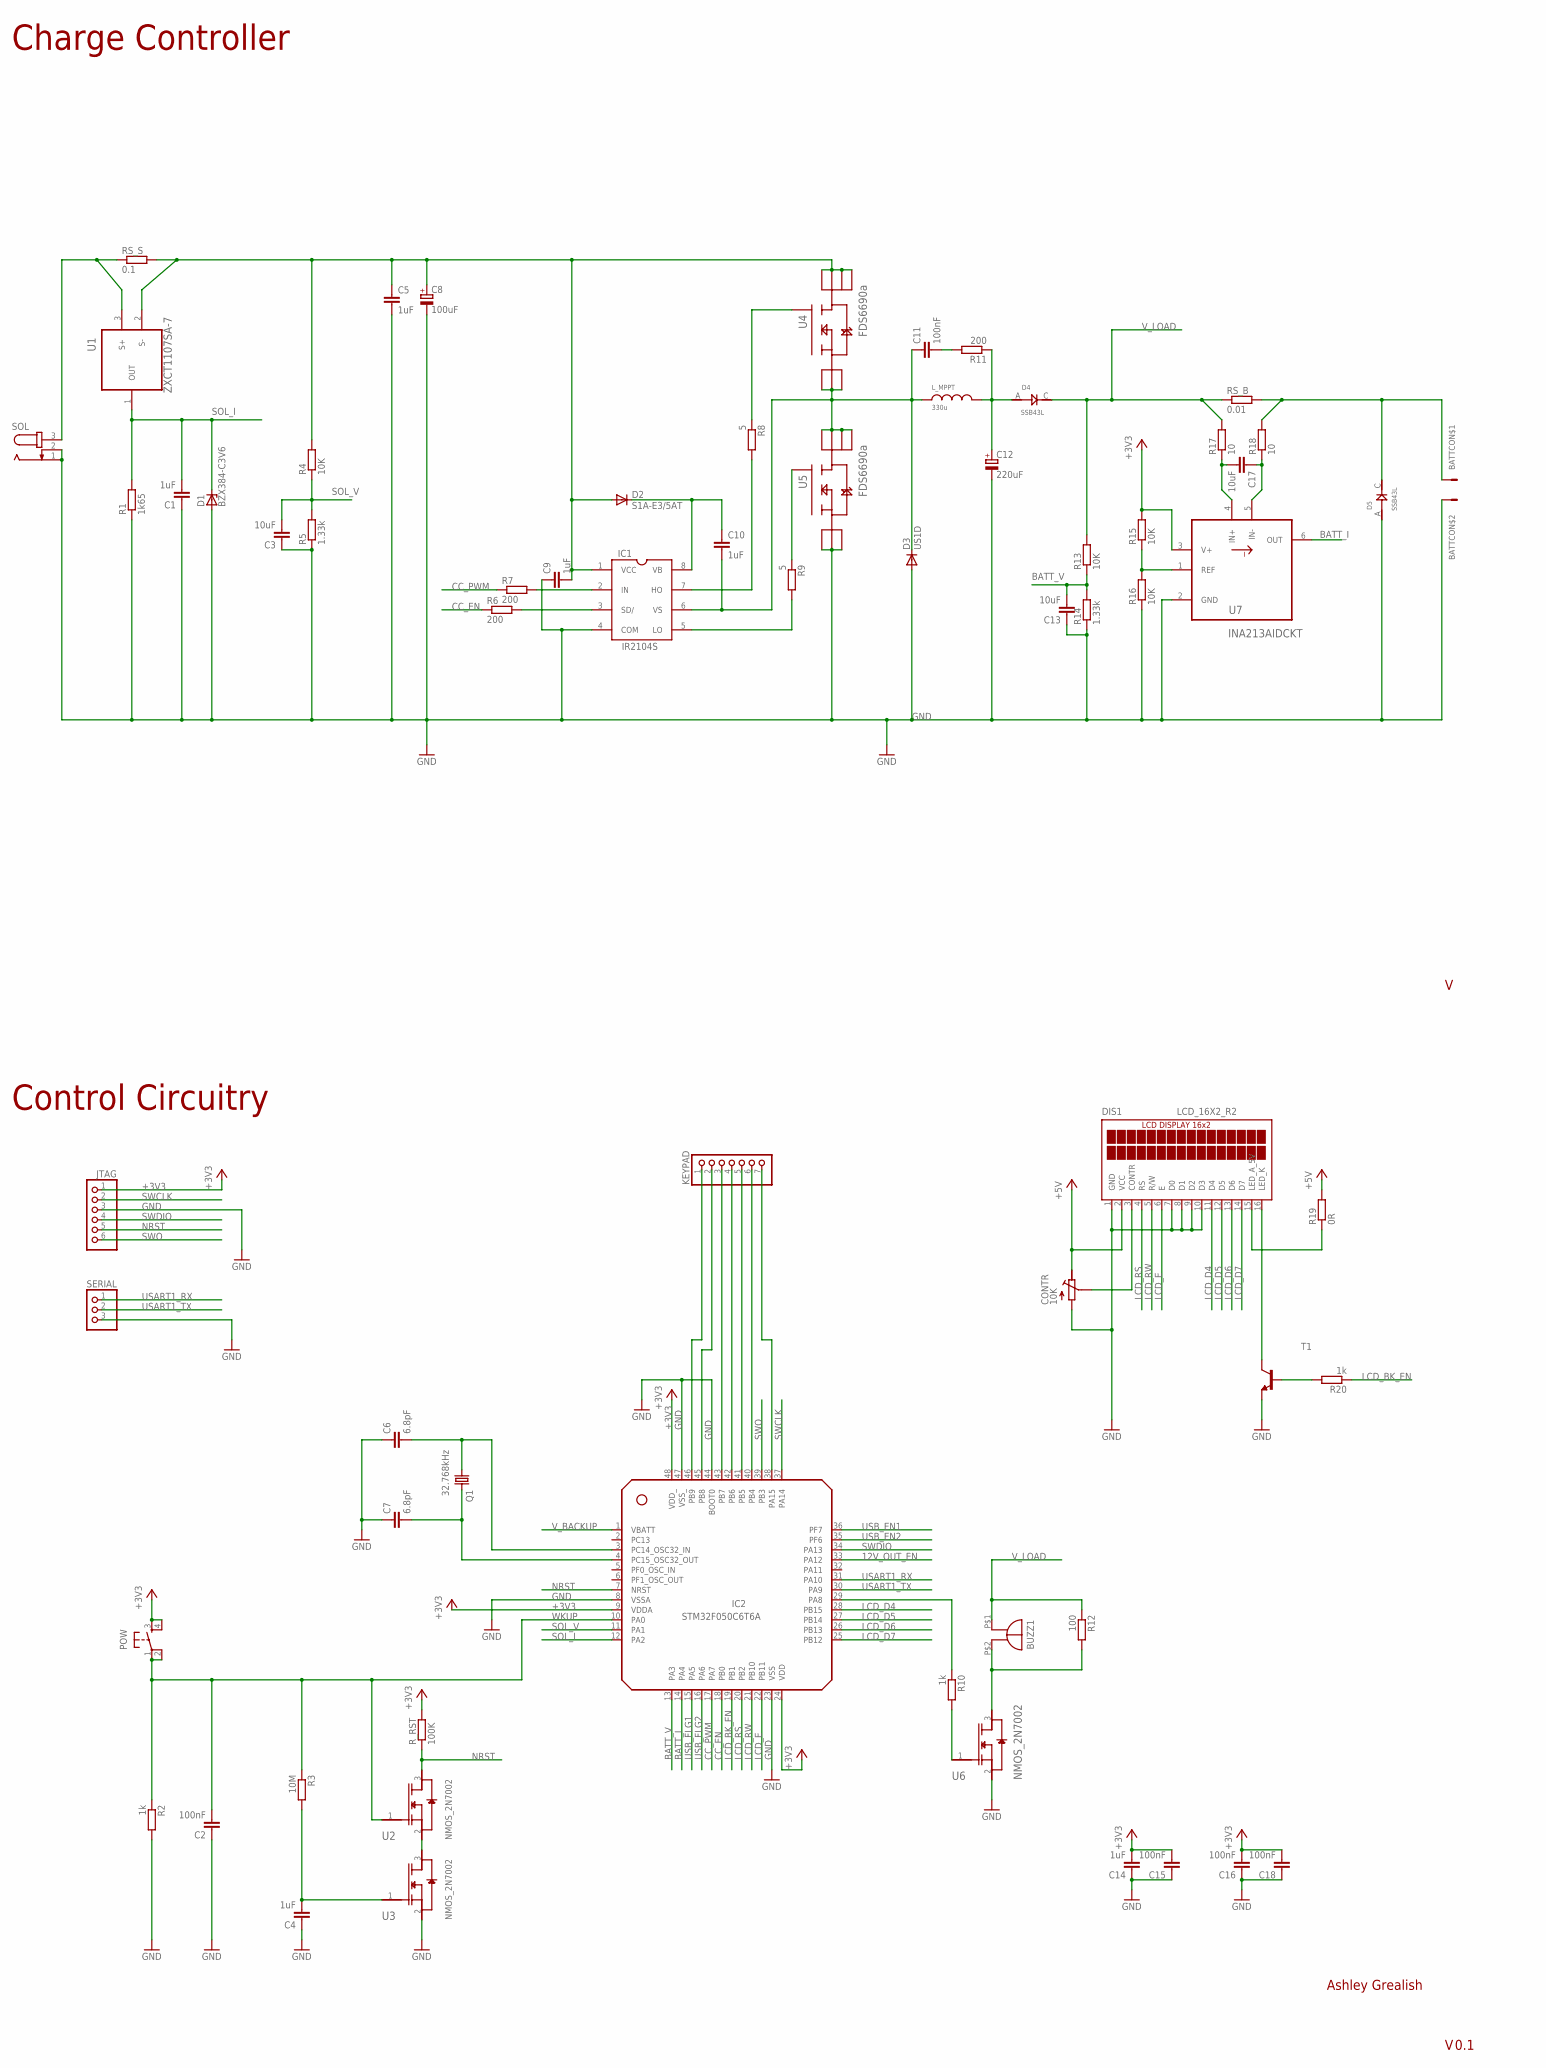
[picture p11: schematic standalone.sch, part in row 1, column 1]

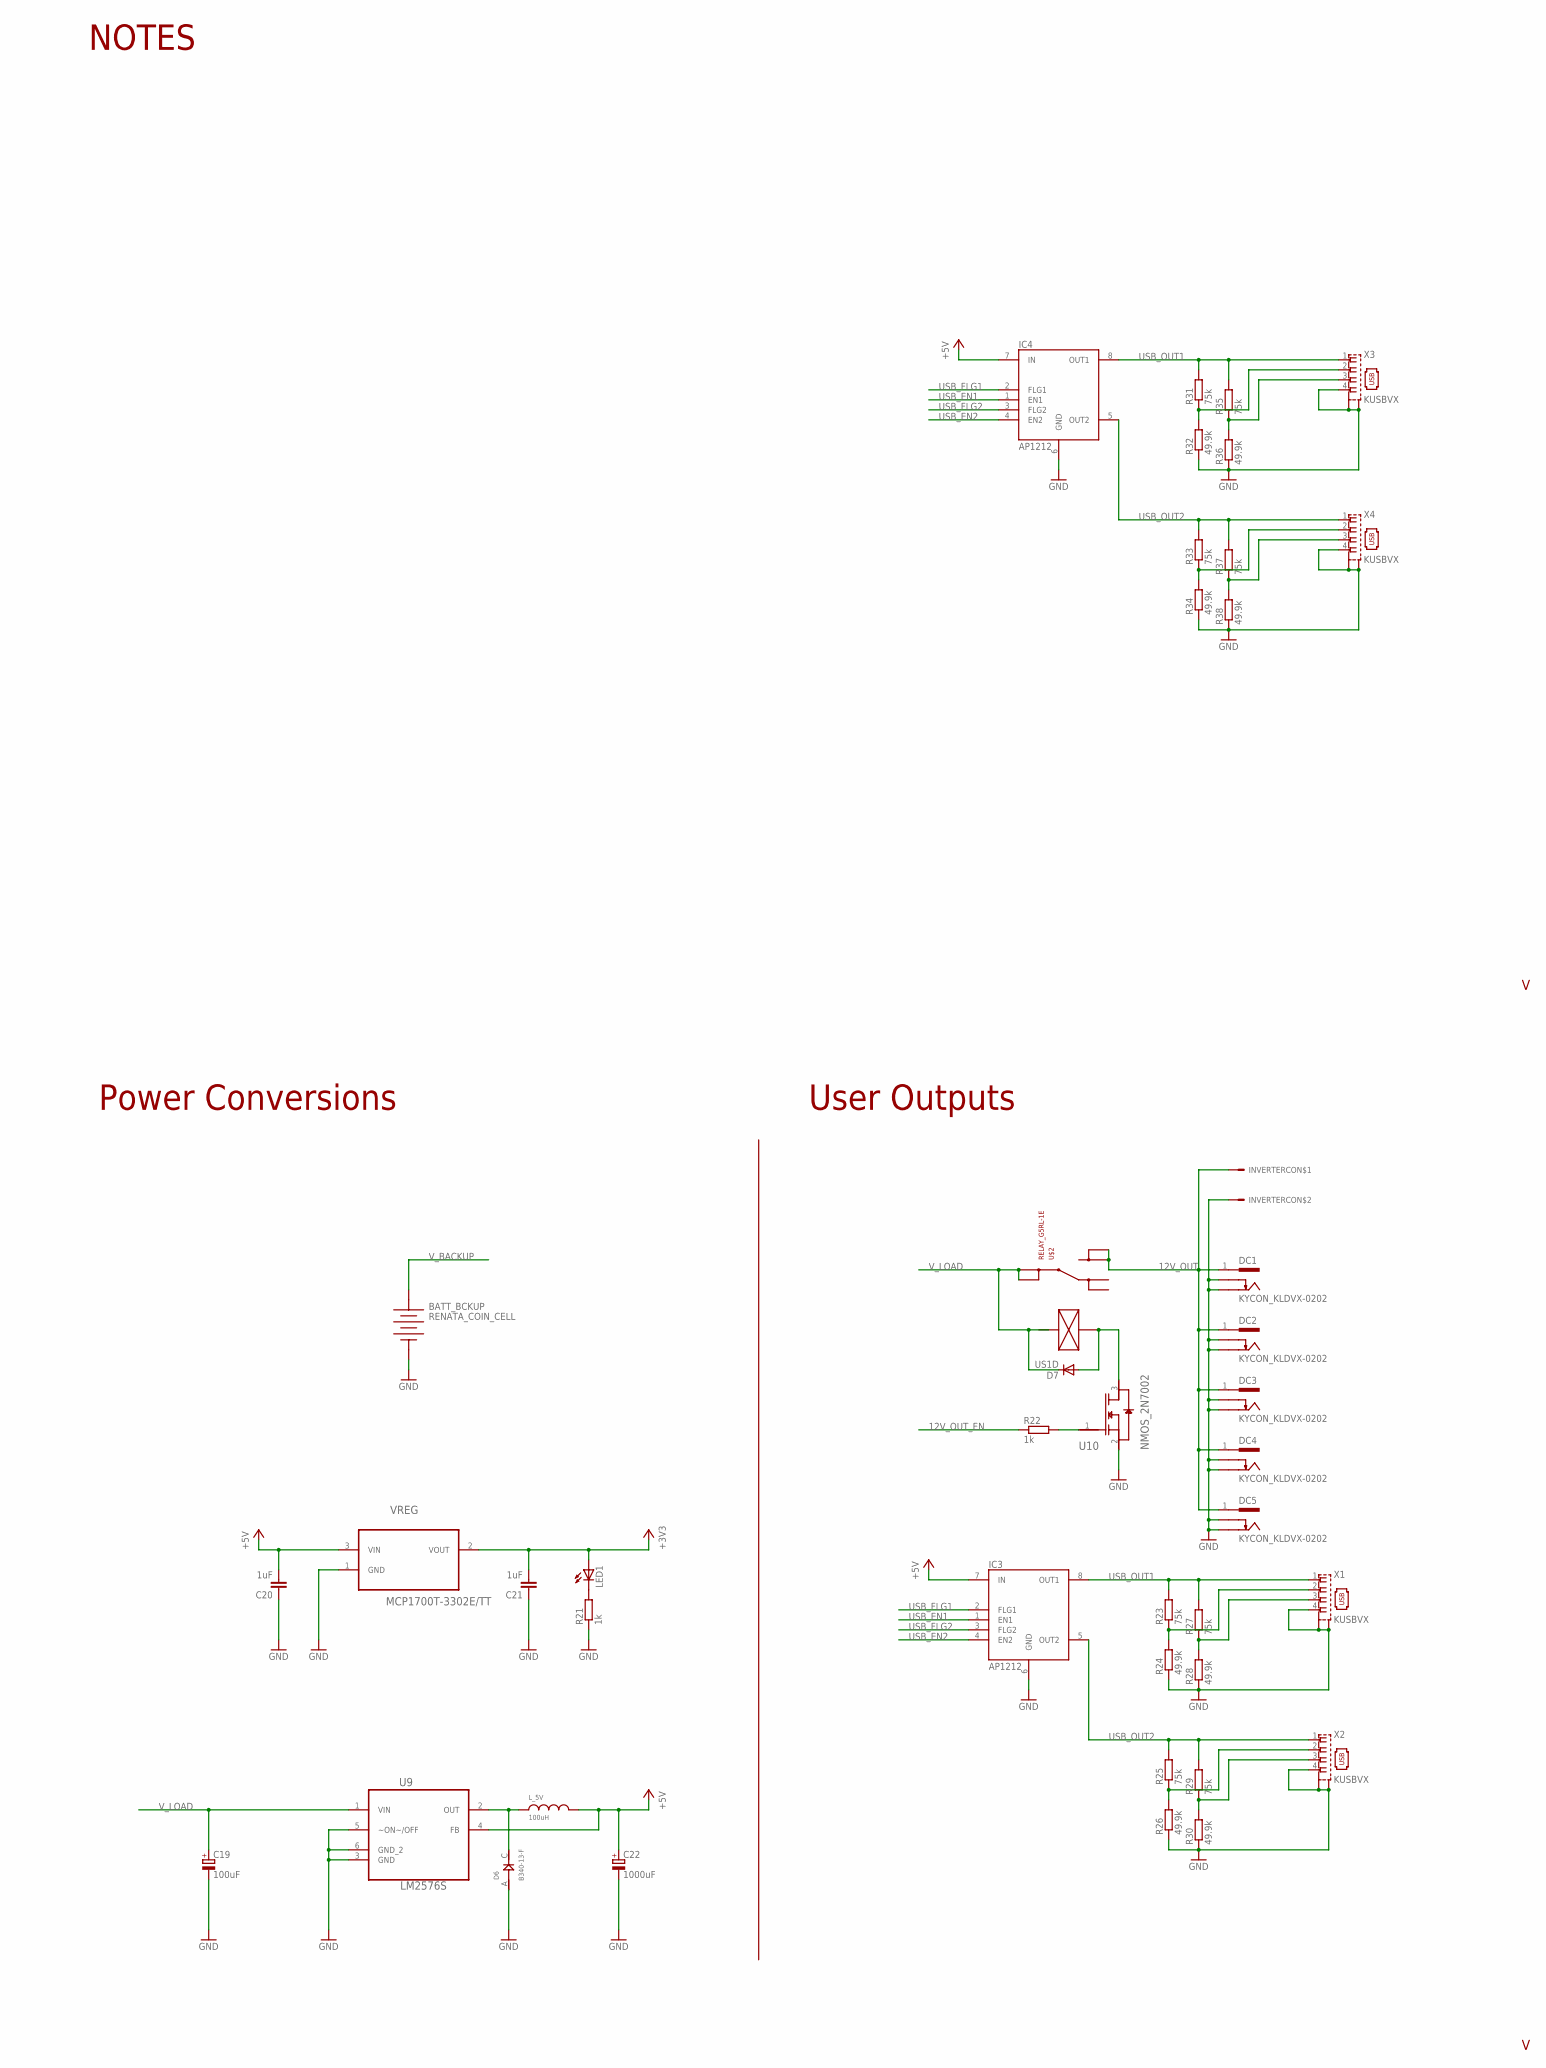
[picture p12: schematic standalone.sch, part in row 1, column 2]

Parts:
BATT: CON_MOLEX_39_29_1028; MOLEX_39_29_1028
BATT_BCKUP: RENATA_COIN_CELL; PANASONIC_CR2032_1298246
BUZZ1: BUZZ_14MM; BUZZ_14MM_5M_PINS
C1, C4, C5, C9, C10, C14, C20, C21: 1uF; C0805K
C2, C11, C15, C16, C18: 100nF; C0805K
C3, C13, C17: 10uF; C0805K
C6, C7: 6.8pF; C0603K
C8, C19: 100uF; PANASONIC_E
C12: 220uF; PANASONIC_F
C22: 1000uF; PANASONIC_G
CONTR: 10K; R_TRIMM_RC33X
D1: BZX384-C3V6; SOD323
D2: S1A-E3/5AT; DO-214AC
D3, D7: US1D; DO-214AC
D4, D5: SSB43L; DO214AA
D6: B340-13-F; SMC
DC1, DC2, DC3, DC4, DC5: KYCON_KLDVX-0202; KYCON_KLVDX_2020_B
DIS1: LCD_16X2_R2
IC1: IR2104S
IC2: STM32F050C6T6A; LQFP48
IC3, IC4: AP1212; SO8
INVERTER: CON_MOLEX_39_29_1028; MOLEX_39_29_1028
JTAG: PINHD-1X6; 1X06
KEYPAD: PINHD-1X7/90; 1X07/90
LED1: POW_3V3; CHIPLED_0805
L_5V: 100uH; INDUC_BOURNS_SDR2207
L_MPPT: 330u; INDUC_MURATA_1433428C
POW: TAC_SWITCHPTH; TACTILE-PTH
Q1: 32.768kHz; MC-306; MPN MC-306
R1: 1k65; M0805
R2, R10, R20, R21, R22: 1k; M0805
R3: 10M; M0805
R4, R13, R15, R16: 10K; M0805
R5, R14: 1.33k; M0805
R6, R7, R11: 200; M0805
R8, R9: 5; M0805
R12: 100; M0805
R17, R18: 10; M0805
R19: 0R; M0805
R23, R25, R27, R29, R31, R33, R35, R37: 75k; M0805
R24, R26, R28, R30, R32, R34, R36, R38: 49.9k; M0805
RS_B: 0.01; R2512
RS_S: 0.1; R2512
R_RST: 100K; M0805
SERIAL: PINHD-1X3; 1X03
SOL: JACK-PLUG0; SPC4077
T1: BC847B-NPN-SOT23-BEC; SOT23-BEC
U1: ZXCT1107SA-7; SOT91P240X110-3N
U2, U3, U6: NMOS_2N7002; SOT103P240X110-3N; MPN 2N7002-7-F
U4, U5: FDS6690a; SOIC127P600X175-8N
U7: INA213AIDCKT; SOT65P210X110-6N
U9: LM2576S; TO263-5
U10: NMOS_2N7002; SOT103P240X110-3N
U$1: EQUINOX_LOGO_LARGE
U$2: RELAY_G5RL-1E; G5RL-1E
VREG: MCP1700T-3302E/TT; SOT95P237X112-3N
X1, X2, X3, X4: KUSBVX

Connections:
12V_OUT: DC1.1, DC2.1, DC3.1, DC4.1, DC5.1, INVERTER.P$1, U$2.NO@1 (NO), U$2.NO@2 (NO)
12V_OUT_EN: IC2.33 (PA12), R22.1
+3V3: C14.2, C15.2, C16.2, C18.2, C21.2, IC2.9 (VDDA), IC2.24 (VDD), IC2.48 (VDD_), JTAG.1, LED1.A, POW.3, POW.4, R15.2, R_RST.2, U7.3 (V+), VREG.2 (VOUT)
+5V: C20.2, C22.+, CONTR.CW (A), DIS1.2 (VCC), IC3.7 (IN), IC4.7 (IN), L_5V.P$2, R19.2, U9.4 (FB), VREG.3 (VIN)
BATT_I: IC2.14 (PA4), U7.6 (OUT)
BATT_V: C13.2, IC2.13 (PA3), R13.1, R14.2
CC_EN: IC2.18 (PB0), R6.1
CC_PWM: IC2.17 (PA7), R7.1
GND: BATT.P$2, BATT_BCKUP.P- (NEG), C1.1, C2.1, C3.1, C4.1, C5.2, C6.1, C7.1, C8.-, C9.1, C12.-, C13.1, C14.1, C15.1, C16.1, C18.1, C19.-, C20.1, C21.1, C22.-, CONTR.CCW (E), D1.A, D3.A, D5.A (ANODE), D6.A (ANODE), DC1.2, DC1.3, DC2.2, DC2.3, DC3.2, DC3.3, DC4.2, DC4.3, DC5.2, DC5.3, DIS1.1 (GND), DIS1.7 (D0), DIS1.8 (D1), DIS1.9 (D2), DIS1.10 (D3), IC1.4 (COM), IC2.8 (VSSA), IC2.23 (VSS), IC2.44 (BOOT0), IC2.47 (VSS_), IC3.6 (GND), IC4.6 (GND), INVERTER.P$2, JTAG.3, R1.1, R2.2, R5.1, R14.1, R16.1, R21.1, R24.1, R26.1, R28.1, R30.1, R32.1, R34.1, R36.1, R38.1, SERIAL.3, SOL.1, SOL.2, T1.E, U3.2 (S), U5.1 (S_2), U5.2 (S_3), U5.3 (S), U6.2 (S), U7.2 (GND), U9.3 (GND), U9.5 (~ON~/OFF), U9.6 (GND_2), U10.2 (S), VREG.1 (GND), X1.4, X1.M1 (S1), X1.M2 (S2), X2.4, X2.M1 (S1), X2.M2 (S2), X3.4, X3.M1 (S1), X3.M2 (S2), X4.4, X4.M1 (S1), X4.M2 (S2)
LCD_BK_EN: IC2.19 (PB1), R20.1
LCD_D4: DIS1.11 (D4), IC2.28 (PB15)
LCD_D5: DIS1.12 (D5), IC2.27 (PB14)
LCD_D6: DIS1.13 (D6), IC2.26 (PB13)
LCD_D7: DIS1.14 (D7), IC2.25 (PB12)
LCD_E: DIS1.6 (E), IC2.22 (PB11)
LCD_RS: DIS1.4 (RS), IC2.20 (PB2)
LCD_RW: DIS1.5 (R/W), IC2.21 (PB10)
unnamed: C6.2, IC2.3 (PC14_OSC32_IN), Q1.1
unnamed: CONTR.WIPE (S), DIS1.3 (CONTR)
unnamed: IC1.3 (SD/), R6.2
unnamed: BATT.P$1, D5.C (CATHODE), R18.2, RS_B.2
unnamed: R31.1, R32.2, X3.2
unnamed: C10.2, C11.1, D3.C, IC1.6 (VS), L_MPPT.P$1, U4.1 (S_2), U4.2 (S_3), U4.3 (S), U5.5 (D_3), U5.6 (D_2), U5.7 (D_4), U5.8 (D)
unnamed: IC1.7 (HO), R8.2
unnamed: IC1.2 (IN), R7.2
unnamed: C10.1, D2.C, IC1.8 (VB)
unnamed: R9.1, U5.4 (G)
unnamed: C12.+, D4.A (ANODE), L_MPPT.P$2, R11.1
unnamed: IC1.5 (LO), R9.2
unnamed: R8.1, U4.4 (G)
unnamed: C11.2, R11.2
unnamed: C5.1, C8.+, C9.2, D2.A, IC1.1 (VCC), R4.2, RS_S.2, U1.2 (S-), U4.5 (D_3), U4.6 (D_2), U4.7 (D_4), U4.8 (D)
unnamed: R35.1, R36.2, X3.3
unnamed: DIS1.15 (LED_A_5V), R19.1
unnamed: R25.1, R26.2, X2.2
unnamed: D6.C (CATHODE), L_5V.P$1, U9.2 (OUT)
unnamed: IC2.29 (PA8), R10.1
unnamed: IC2.46 (PB9), KEYPAD.1
unnamed: IC2.45 (PB8), KEYPAD.2
unnamed: IC2.43 (PB7), KEYPAD.3
unnamed: IC2.42 (PB6), KEYPAD.4
unnamed: IC2.41 (PB5), KEYPAD.5
unnamed: IC2.40 (PB4), KEYPAD.6
unnamed: IC2.38 (PA15), KEYPAD.7
unnamed: DIS1.16 (LED_K), T1.C
unnamed: R20.2, T1.B
unnamed: R23.1, R24.2, X1.2
unnamed: R27.1, R28.2, X1.3
unnamed: R22.2, U10.1 (G)
unnamed: R29.1, R30.2, X2.3
unnamed: LED1.C, R21.2
unnamed: RS_S.1, SOL.3, U1.3 (S+)
unnamed: R15.1, R16.2, U7.1 (REF)
unnamed: C17.2, R17.1, U7.4 (IN+)
unnamed: C17.1, R18.1, U7.5 (IN-)
unnamed: BUZZ1.P$2 (-), R12.2, U6.3 (D)
unnamed: R10.2, U6.1 (G)
unnamed: C4.2, R3.2, U3.1 (G)
unnamed: U2.2 (S), U3.3 (D)
unnamed: R33.1, R34.2, X4.2
unnamed: R37.1, R38.2, X4.3
unnamed: C7.2, IC2.4 (PC15_OSC32_OUT), Q1.4 (2)
unnamed: D7.A, U10.3 (D), U$2.COIL+
NRST: IC2.7 (NRST), JTAG.5, R_RST.1, U2.3 (D)
SOL_I: C1.2, D1.C, IC2.12 (PA2), R1.2, U1.1 (OUT)
SOL_V: C3.2, IC2.11 (PA1), R4.1, R5.2
SWCLK: IC2.37 (PA14), JTAG.2
SWDIO: IC2.34 (PA13), JTAG.4
SWO: IC2.39 (PB3), JTAG.6
USART1_RX: IC2.31 (PA10), SERIAL.1
USART1_TX: IC2.30 (PA9), SERIAL.2
USB_EN1: IC2.36 (PF7), IC3.1 (EN1), IC4.1 (EN1)
USB_EN2: IC2.35 (PF6), IC3.4 (EN2), IC4.4 (EN2)
USB_FLG1: IC2.15 (PA5), IC3.2 (FLG1), IC4.2 (FLG1)
USB_FLG2: IC2.16 (PA6), IC3.3 (FLG2), IC4.3 (FLG2)
USB_OUT1: IC3.8 (OUT1), IC4.8 (OUT1), R23.2, R27.2, R31.2, R35.2, X1.1, X3.1
USB_OUT2: IC3.5 (OUT2), IC4.5 (OUT2), R25.2, R29.2, R33.2, R37.2, X2.1, X4.1
V_BACKUP: BATT_BCKUP.P+ (POS), IC2.1 (VBATT)
V_LOAD: BUZZ1.P$1 (+), C19.+, D4.C (CATHODE), D7.C, R12.1, R13.2, R17.2, RS_B.1, U9.1 (VIN), U$2.COM@1 (COM), U$2.COM@2 (COM)
WKUP: C2.2, IC2.10 (PA0), POW.1, POW.2, R2.1, R3.1, U2.1 (G)

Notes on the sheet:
Charge Controller
Control Circuitry
Power Conversions
User Outputs
NOTES

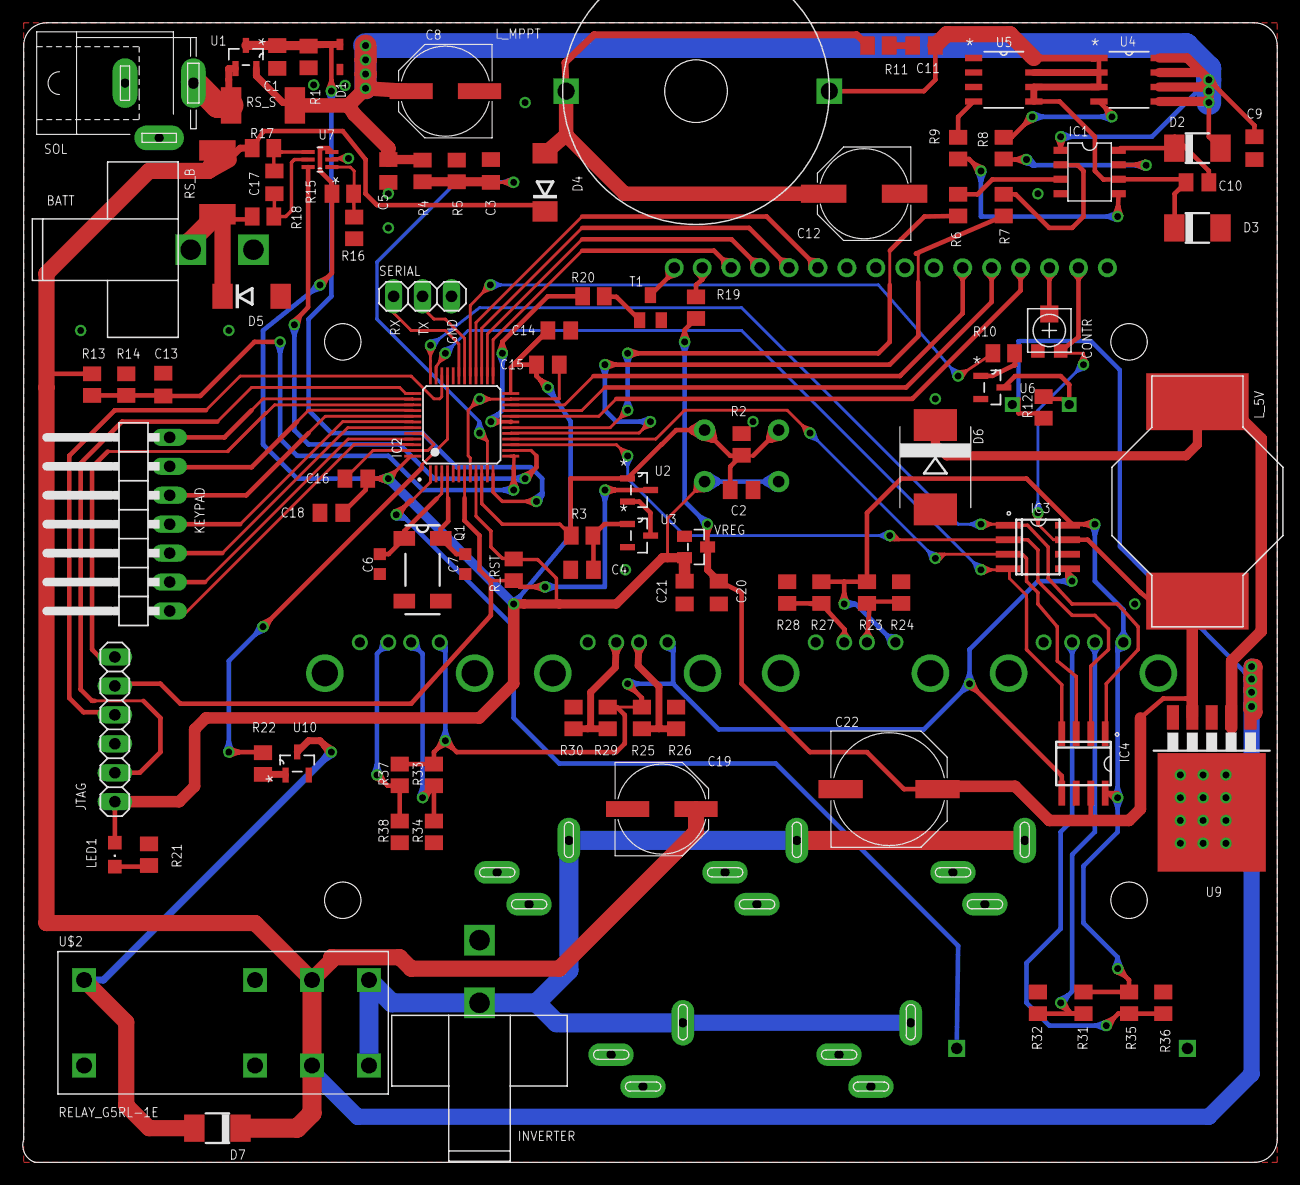
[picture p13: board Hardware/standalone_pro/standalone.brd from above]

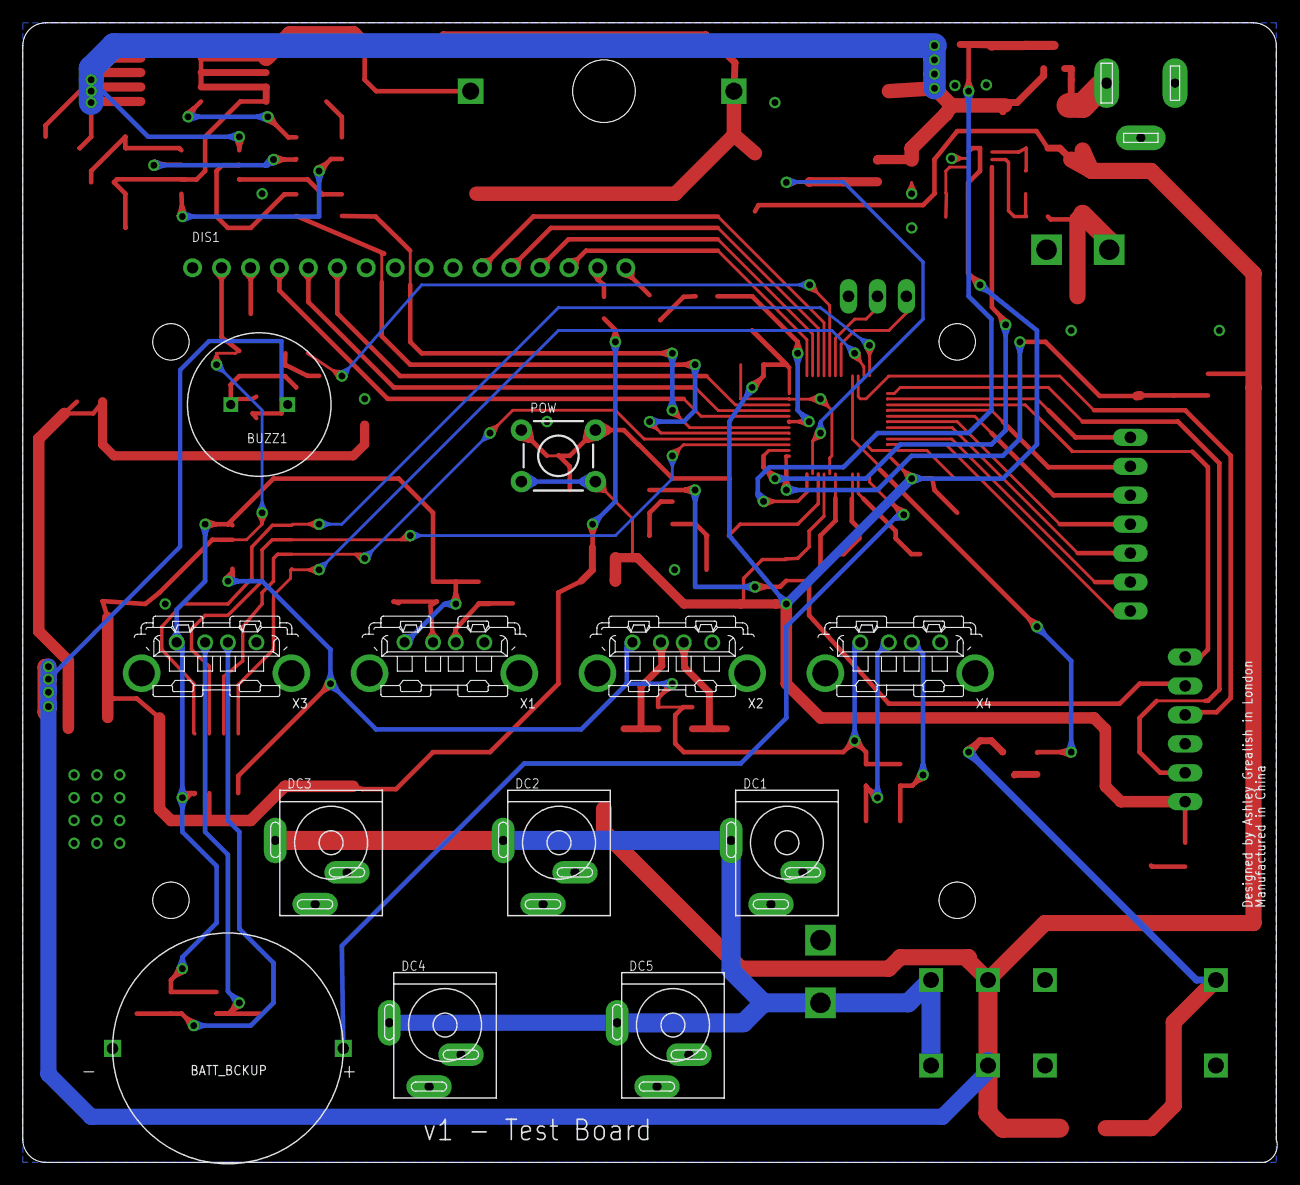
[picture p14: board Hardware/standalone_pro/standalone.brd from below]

Board: 2 copper layers, 110.1 x 100.0 mm, 111 parts (14 on the bottom side), 80 nets.

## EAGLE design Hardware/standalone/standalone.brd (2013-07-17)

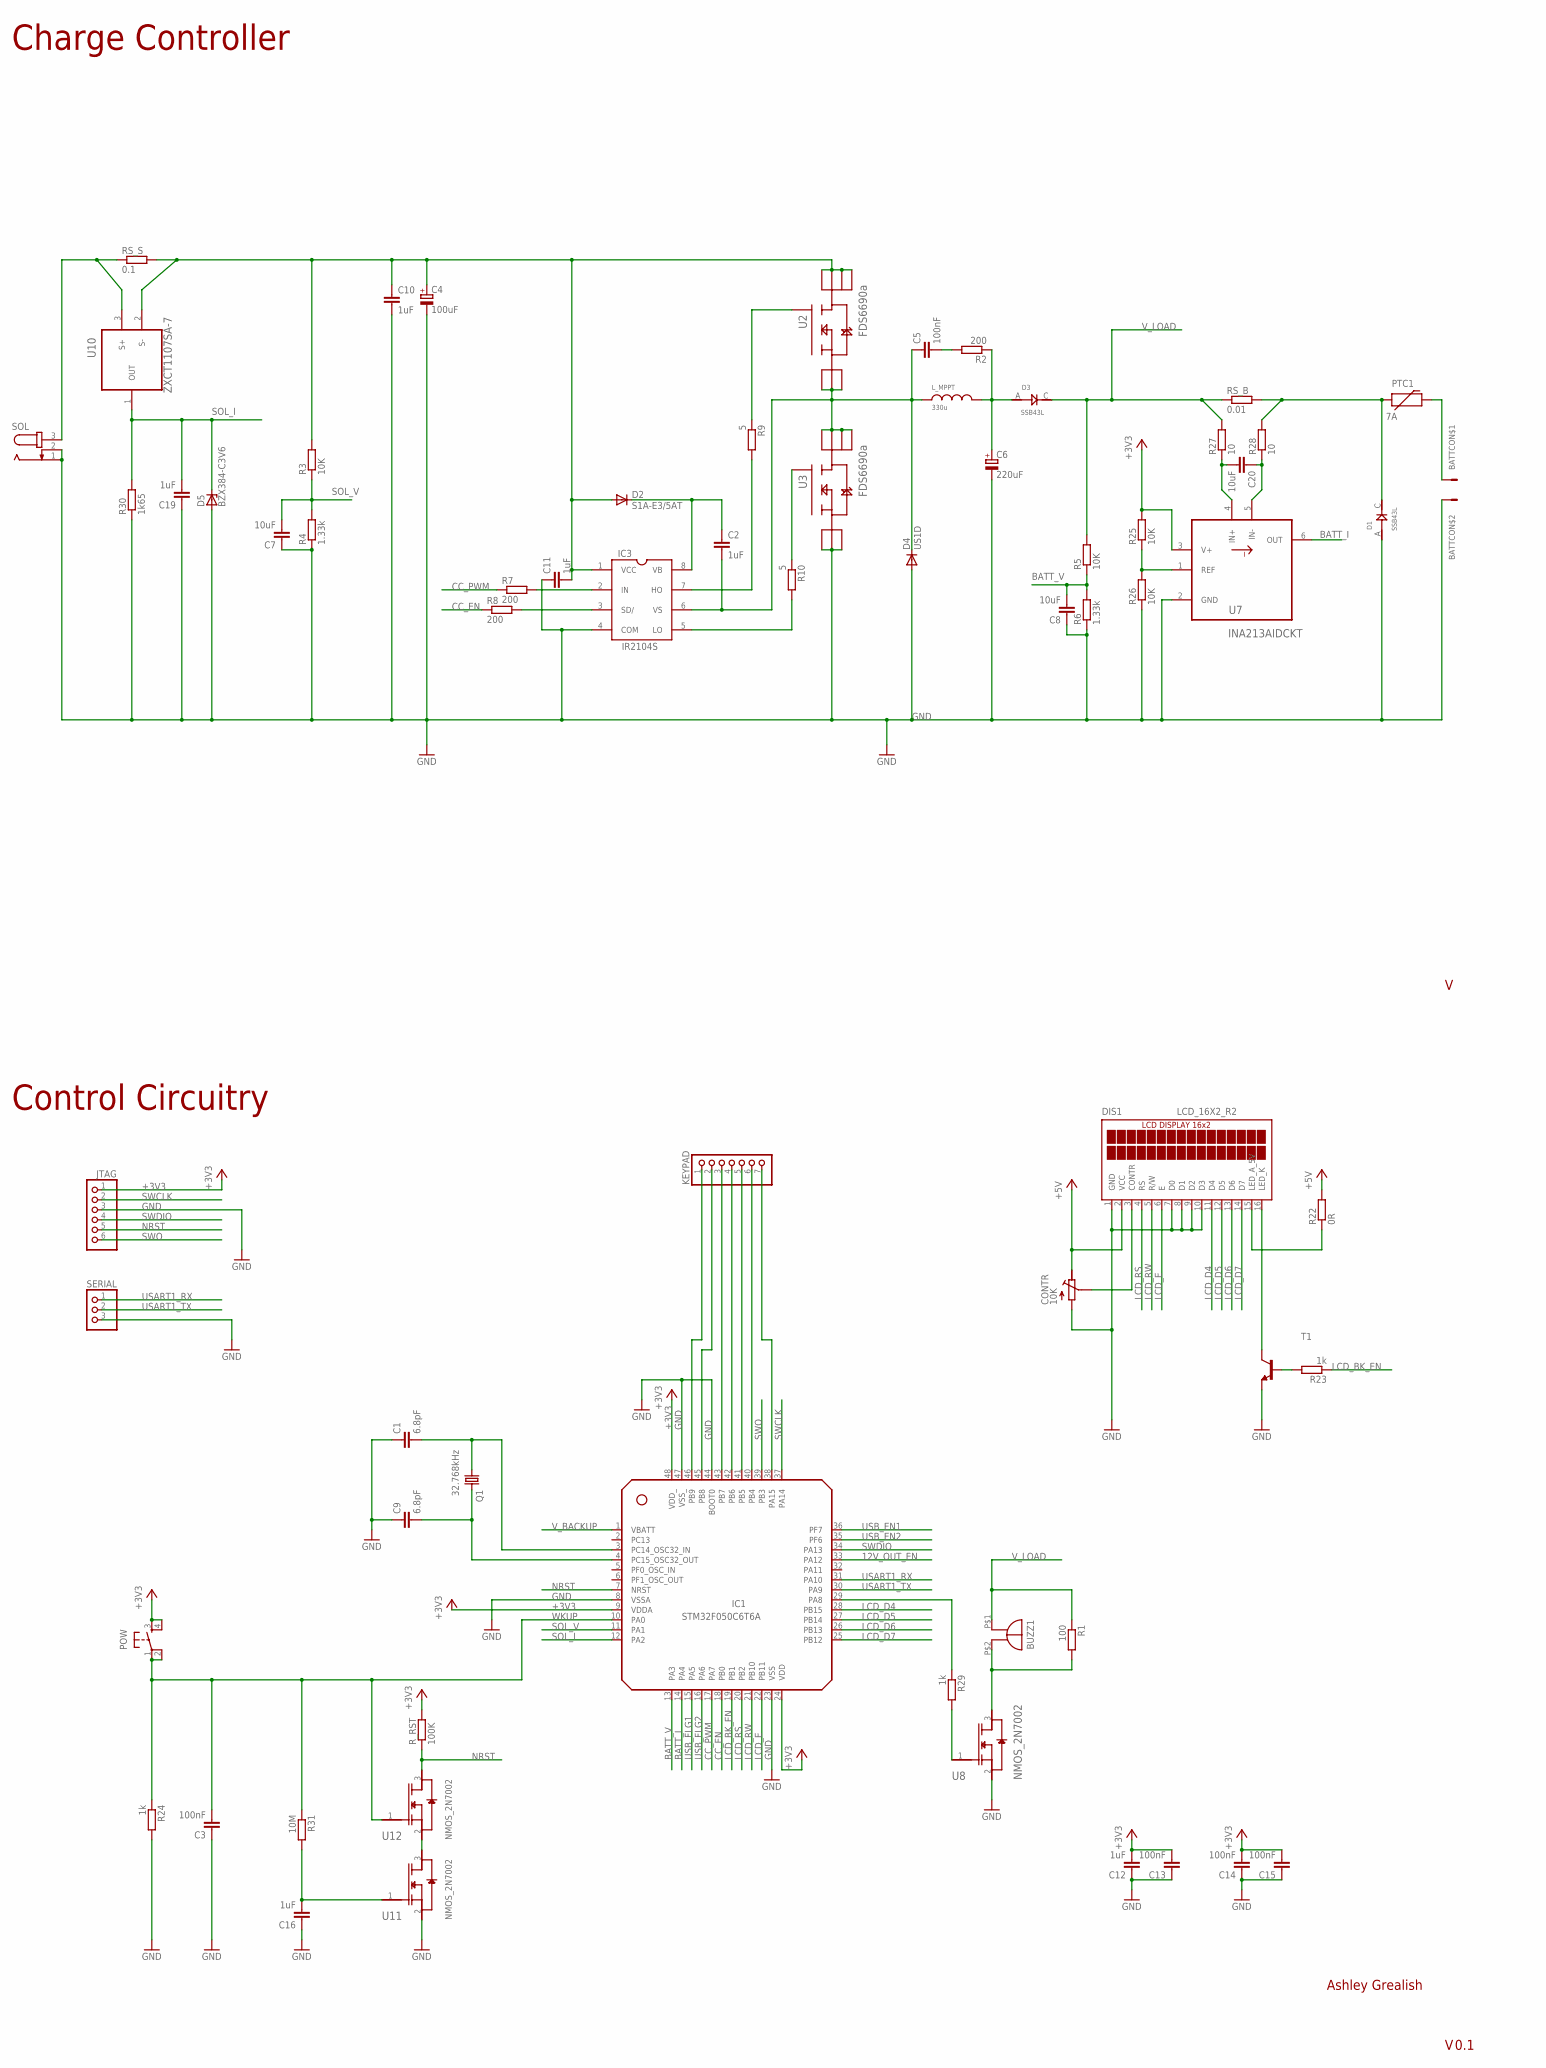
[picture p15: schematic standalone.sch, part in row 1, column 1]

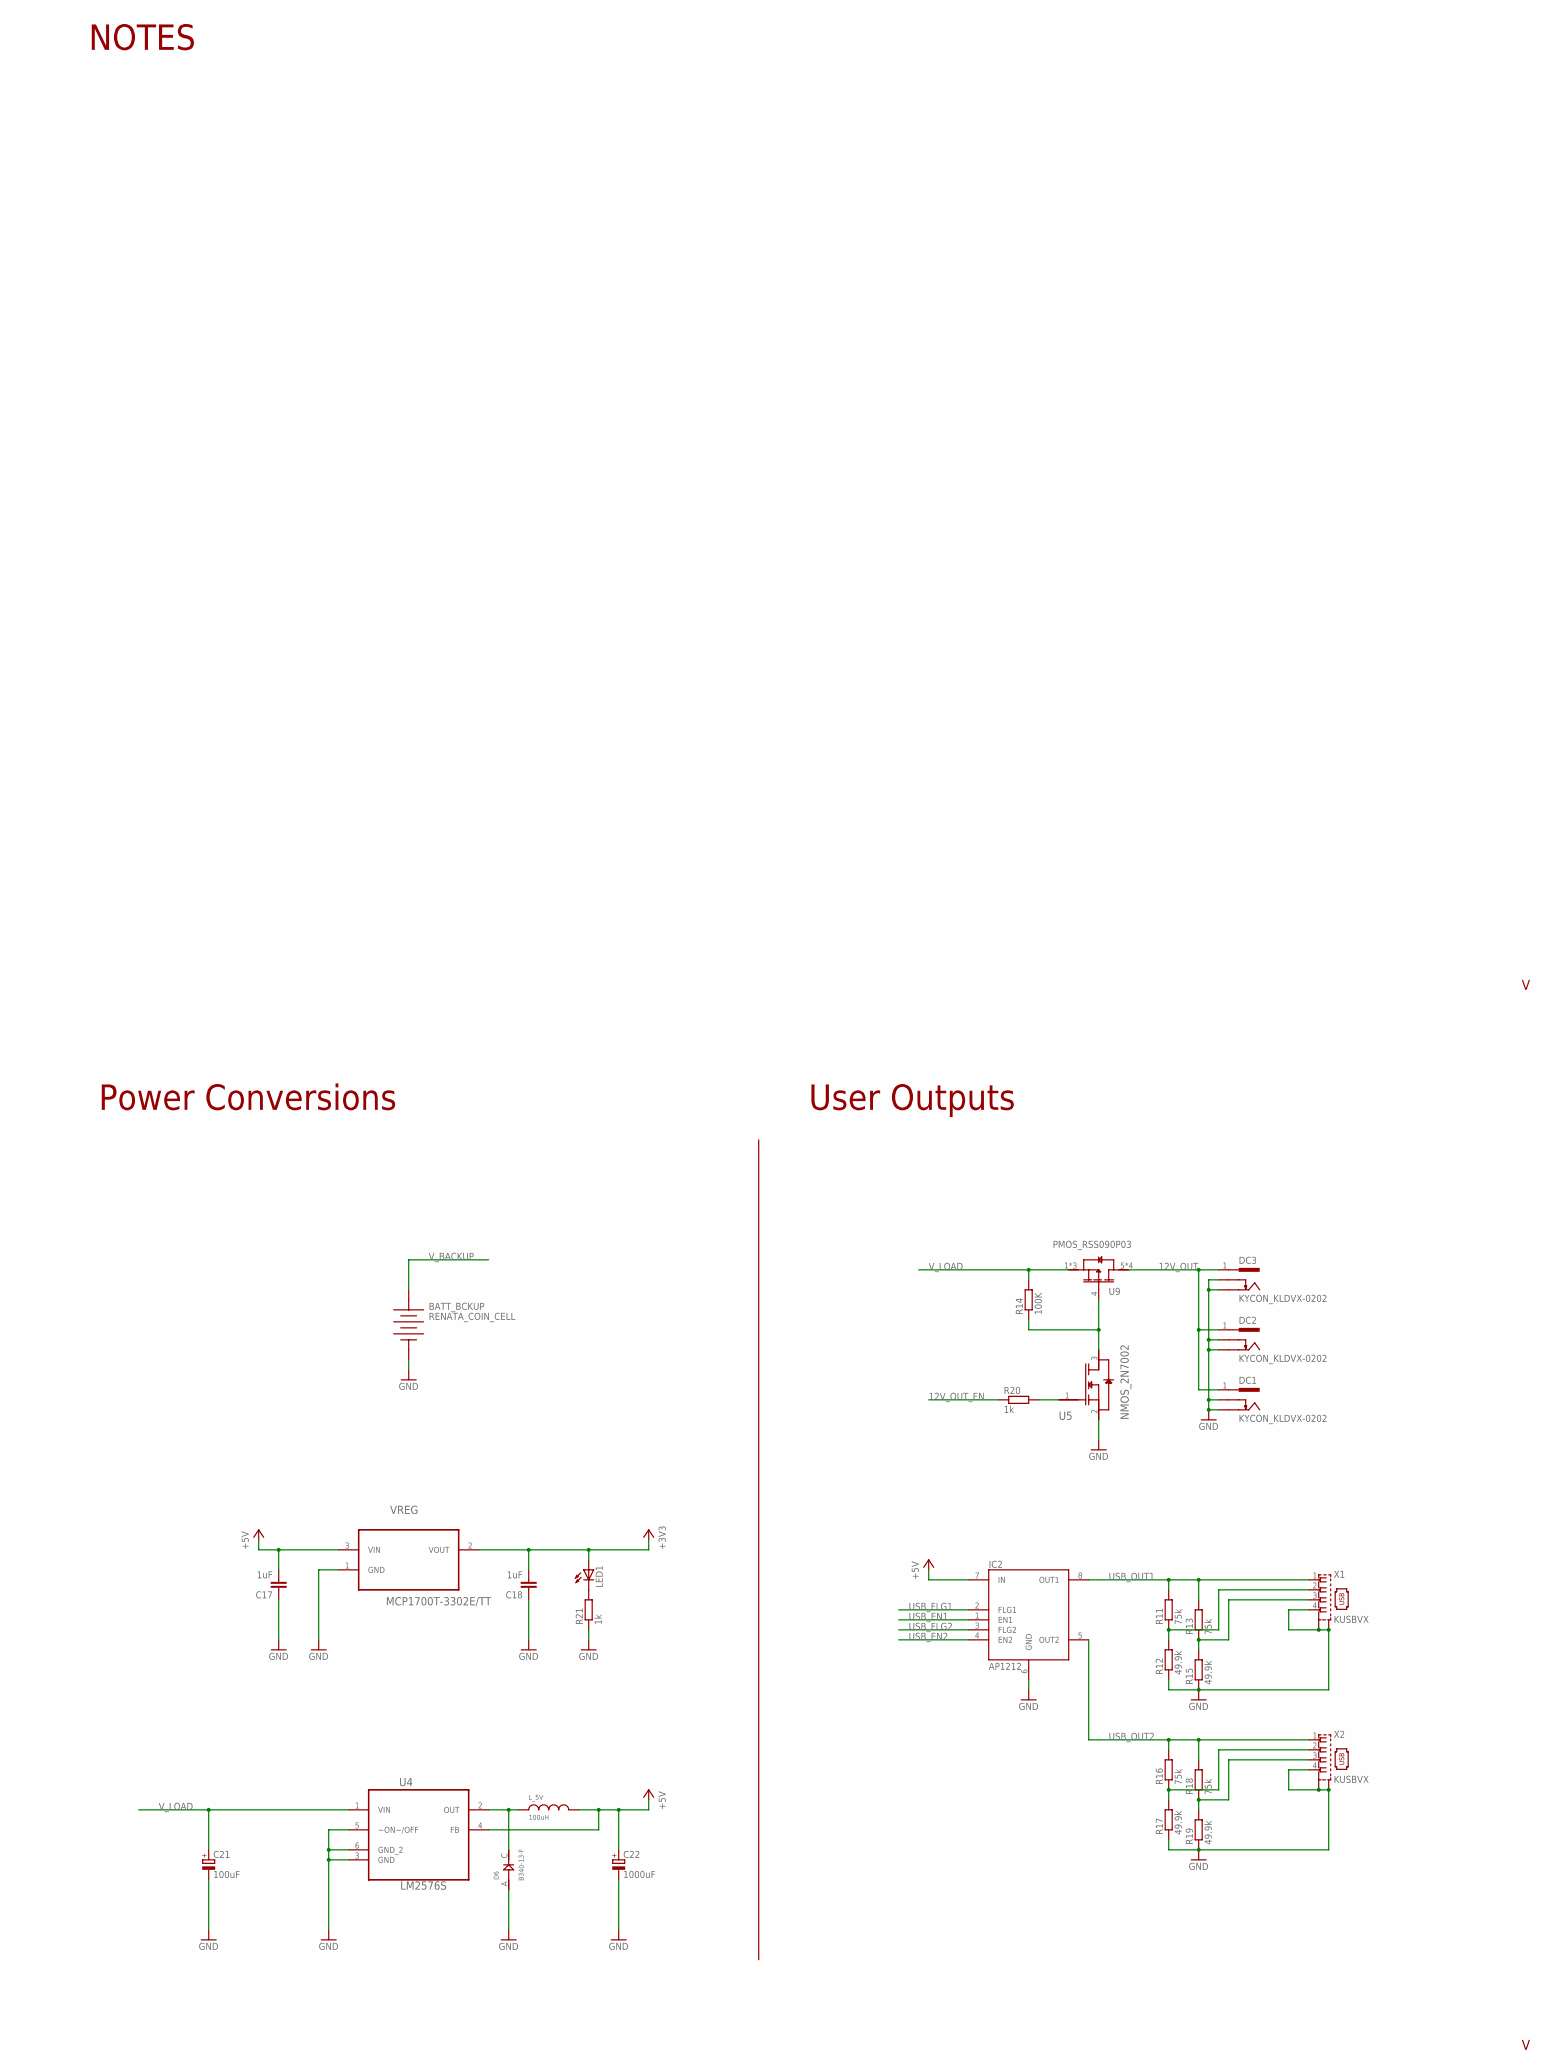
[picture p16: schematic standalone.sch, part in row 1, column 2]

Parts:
BATT: CON_MOLEX_39_29_1028; MOLEX_39_29_1028
BATT_BCKUP: RENATA_COIN_CELL; PANASONIC_CR2032_1298246
BUZZ1: BUZZ_14MM; BUZZ_14MM_5M_PINS
C1, C9: 6.8pF; C0603K
C2, C10, C11, C12, C16, C17, C18, C19: 1uF; C0805K
C3, C5, C13, C14, C15: 100nF; C0805K
C4, C21: 100uF; PANASONIC_E
C6: 220uF; PANASONIC_F
C7, C8, C20: 10uF; C0805K
C22: 1000uF; PANASONIC_G
CONTR: 10K; R_TRIMM_RC33X
D1, D3: SSB43L; DO214AA
D2: S1A-E3/5AT; DO-214AC
D4: US1D; DO-214AC
D5: BZX384-C3V6; SOD323
D6: B340-13-F; SMC
DC1, DC2, DC3: KYCON_KLDVX-0202; KYCON_KLVDX_2020_B
DIS1: LCD_16X2_R2
IC1: STM32F050C6T6A; LQFP48
IC2: AP1212; SO8
IC3: IR2104S
JTAG: PINHD-1X6; 1X06
KEYPAD: PINHD-1X7/90; 1X07/90
LED1: POW_3V3; CHIPLED_0805
L_5V: 100uH; INDUC_BOURNS_SDR2207
L_MPPT: 330u; INDUC_BOURNS_SDR1806
POW: TAC_SWITCHPTH; TACTILE-PTH
PTC1: 7A; PTC_MF_R700
Q1: 32.768kHz; MC-306; MPN MC-306
R1: 100; M0805
R2, R7, R8: 200; M0805
R3, R5, R25, R26: 10K; M0805
R4, R6: 1.33k; M0805
R9, R10: 5; M0805
R11, R13, R16, R18: 75k; M0805
R12, R15, R17, R19: 49.9k; M0805
R14: 100K; M0805
R20, R21, R23, R24, R29: 1k; M0805
R22: 0R; M0805
R27, R28: 10; M0805
R30: 1k65; M0805
R31: 10M; M0805
RS_B: 0.01; R2512
RS_S: 0.1; R2512
R_RST: 100K; M0805
SERIAL: PINHD-1X3; 1X03
SOL: JACK-PLUG0; SPC4077
T1: BC847B-NPN-SOT23-BEC; SOT23-BEC
U2, U3: FDS6690a; SOIC127P600X175-8N
U4: LM2576S; TO263-5
U5: NMOS_2N7002; SOT103P240X110-3N
U7: INA213AIDCKT; SOT65P210X110-6N
U8, U11, U12: NMOS_2N7002; SOT103P240X110-3N; MPN 2N7002-7-F
U9: PMOS_RSS090P03; SO8
U10: ZXCT1107SA-7; SOT91P240X110-3N
U$1: EQUINOX_LOGO_LARGE
VREG: MCP1700T-3302E/TT; SOT95P237X112-3N
X1, X2: KUSBVX

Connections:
12V_OUT: DC1.1, DC2.1, DC3.1, U9.5 (D2), U9.6 (D2), U9.7 (D2), U9.8 (D2)
12V_OUT_EN: IC1.33 (PA12), R20.1
+3V3: C12.2, C13.2, C14.2, C15.2, C18.2, IC1.9 (VDDA), IC1.24 (VDD), IC1.48 (VDD_), JTAG.1, LED1.A, POW.3, POW.4, R25.2, R_RST.2, U7.3 (V+), VREG.2 (VOUT)
+5V: C17.2, C22.+, CONTR.CW (A), DIS1.2 (VCC), IC2.7 (IN), L_5V.P$2, R22.2, U4.4 (FB), VREG.3 (VIN)
BATT_I: IC1.14 (PA4), U7.6 (OUT)
BATT_V: C8.2, IC1.13 (PA3), R5.1, R6.2
CC_EN: IC1.18 (PB0), R8.1
CC_PWM: IC1.17 (PA7), R7.1
GND: BATT.P$2, BATT_BCKUP.P- (NEG), C1.1, C3.1, C4.-, C6.-, C7.1, C8.1, C9.1, C10.2, C11.1, C12.1, C13.1, C14.1, C15.1, C16.1, C17.1, C18.1, C19.1, C21.-, C22.-, CONTR.CCW (E), D1.A (ANODE), D4.A, D5.A, D6.A (ANODE), DC1.2, DC1.3, DC2.2, DC2.3, DC3.2, DC3.3, DIS1.1 (GND), DIS1.7 (D0), DIS1.8 (D1), DIS1.9 (D2), DIS1.10 (D3), IC1.8 (VSSA), IC1.23 (VSS), IC1.44 (BOOT0), IC1.47 (VSS_), IC2.6 (GND), IC3.4 (COM), JTAG.3, R4.1, R6.1, R12.1, R15.1, R17.1, R19.1, R21.1, R24.2, R26.1, R30.1, SERIAL.3, SOL.1, SOL.2, T1.E, U3.1 (S_2), U3.2 (S_3), U3.3 (S), U4.3 (GND), U4.5 (~ON~/OFF), U4.6 (GND_2), U5.2 (S), U7.2 (GND), U8.2 (S), U11.2 (S), VREG.1 (GND), X1.4, X1.M1 (S1), X1.M2 (S2), X2.4, X2.M1 (S1), X2.M2 (S2)
LCD_BK_EN: IC1.19 (PB1), R23.1
LCD_D4: DIS1.11 (D4), IC1.28 (PB15)
LCD_D5: DIS1.12 (D5), IC1.27 (PB14)
LCD_D6: DIS1.13 (D6), IC1.26 (PB13)
LCD_D7: DIS1.14 (D7), IC1.25 (PB12)
LCD_E: DIS1.6 (E), IC1.22 (PB11)
LCD_RS: DIS1.4 (RS), IC1.20 (PB2)
LCD_RW: DIS1.5 (R/W), IC1.21 (PB10)
unnamed: C1.2, IC1.3 (PC14_OSC32_IN), Q1.1
unnamed: CONTR.WIPE (S), DIS1.3 (CONTR)
unnamed: IC3.3 (SD/), R8.2
unnamed: D1.C (CATHODE), PTC1.P$1, R28.2, RS_B.2
unnamed: C2.2, C5.1, D4.C, IC3.6 (VS), L_MPPT.P$1, U2.1 (S_2), U2.2 (S_3), U2.3 (S), U3.5 (D_3), U3.6 (D_2), U3.7 (D_4), U3.8 (D)
unnamed: IC3.7 (HO), R9.2
unnamed: IC3.2 (IN), R7.2
unnamed: C2.1, D2.C, IC3.8 (VB)
unnamed: R10.1, U3.4 (G)
unnamed: C6.+, D3.A (ANODE), L_MPPT.P$2, R2.1
unnamed: IC3.5 (LO), R10.2
unnamed: R9.1, U2.4 (G)
unnamed: C5.2, R2.2
unnamed: C4.+, C10.1, C11.2, D2.A, IC3.1 (VCC), R3.2, RS_S.2, U2.5 (D_3), U2.6 (D_2), U2.7 (D_4), U2.8 (D), U10.2 (S-)
unnamed: C9.2, IC1.4 (PC15_OSC32_OUT), Q1.4 (2)
unnamed: DIS1.15 (LED_A_5V), R22.1
unnamed: R16.1, R17.2, X2.2
unnamed: D6.C (CATHODE), L_5V.P$1, U4.2 (OUT)
unnamed: IC1.29 (PA8), R29.1
unnamed: IC1.46 (PB9), KEYPAD.1
unnamed: IC1.45 (PB8), KEYPAD.2
unnamed: R14.1, U5.3 (D), U9.4 (G)
unnamed: IC1.43 (PB7), KEYPAD.3
unnamed: IC1.42 (PB6), KEYPAD.4
unnamed: IC1.41 (PB5), KEYPAD.5
unnamed: IC1.40 (PB4), KEYPAD.6
unnamed: IC1.38 (PA15), KEYPAD.7
unnamed: DIS1.16 (LED_K), T1.C
unnamed: R23.2, T1.B
unnamed: R11.1, R12.2, X1.2
unnamed: R13.1, R15.2, X1.3
unnamed: R20.2, U5.1 (G)
unnamed: R18.1, R19.2, X2.3
unnamed: LED1.C, R21.2
unnamed: RS_S.1, SOL.3, U10.3 (S+)
unnamed: R25.1, R26.2, U7.1 (REF)
unnamed: C20.2, R27.1, U7.4 (IN+)
unnamed: C20.1, R28.1, U7.5 (IN-)
unnamed: BUZZ1.P$2 (-), R1.2, U8.3 (D)
unnamed: R29.2, U8.1 (G)
unnamed: C16.2, R31.2, U11.1 (G)
unnamed: U11.3 (D), U12.2 (S)
unnamed: BATT.P$1, PTC1.P$2
NRST: IC1.7 (NRST), JTAG.5, R_RST.1, U12.3 (D)
SOL_I: C19.2, D5.C, IC1.12 (PA2), R30.2, U10.1 (OUT)
SOL_V: C7.2, IC1.11 (PA1), R3.1, R4.2
SWCLK: IC1.37 (PA14), JTAG.2
SWDIO: IC1.34 (PA13), JTAG.4
SWO: IC1.39 (PB3), JTAG.6
USART1_RX: IC1.31 (PA10), SERIAL.1
USART1_TX: IC1.30 (PA9), SERIAL.2
USB_EN1: IC1.36 (PF7), IC2.1 (EN1)
USB_EN2: IC1.35 (PF6), IC2.4 (EN2)
USB_FLG1: IC1.15 (PA5), IC2.2 (FLG1)
USB_FLG2: IC1.16 (PA6), IC2.3 (FLG2)
USB_OUT1: IC2.8 (OUT1), R11.2, R13.2, X1.1
USB_OUT2: IC2.5 (OUT2), R16.2, R18.2, X2.1
V_BACKUP: BATT_BCKUP.P+ (POS), IC1.1 (VBATT)
V_LOAD: BUZZ1.P$1 (+), C21.+, D3.C (CATHODE), R1.1, R5.2, R14.2, R27.2, RS_B.1, U4.1 (VIN), U9.1 (S2), U9.2 (S2), U9.3 (S2)
WKUP: C3.2, IC1.10 (PA0), POW.1, POW.2, R24.1, R31.1, U12.1 (G)

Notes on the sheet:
Charge Controller
Control Circuitry
Power Conversions
User Outputs
NOTES

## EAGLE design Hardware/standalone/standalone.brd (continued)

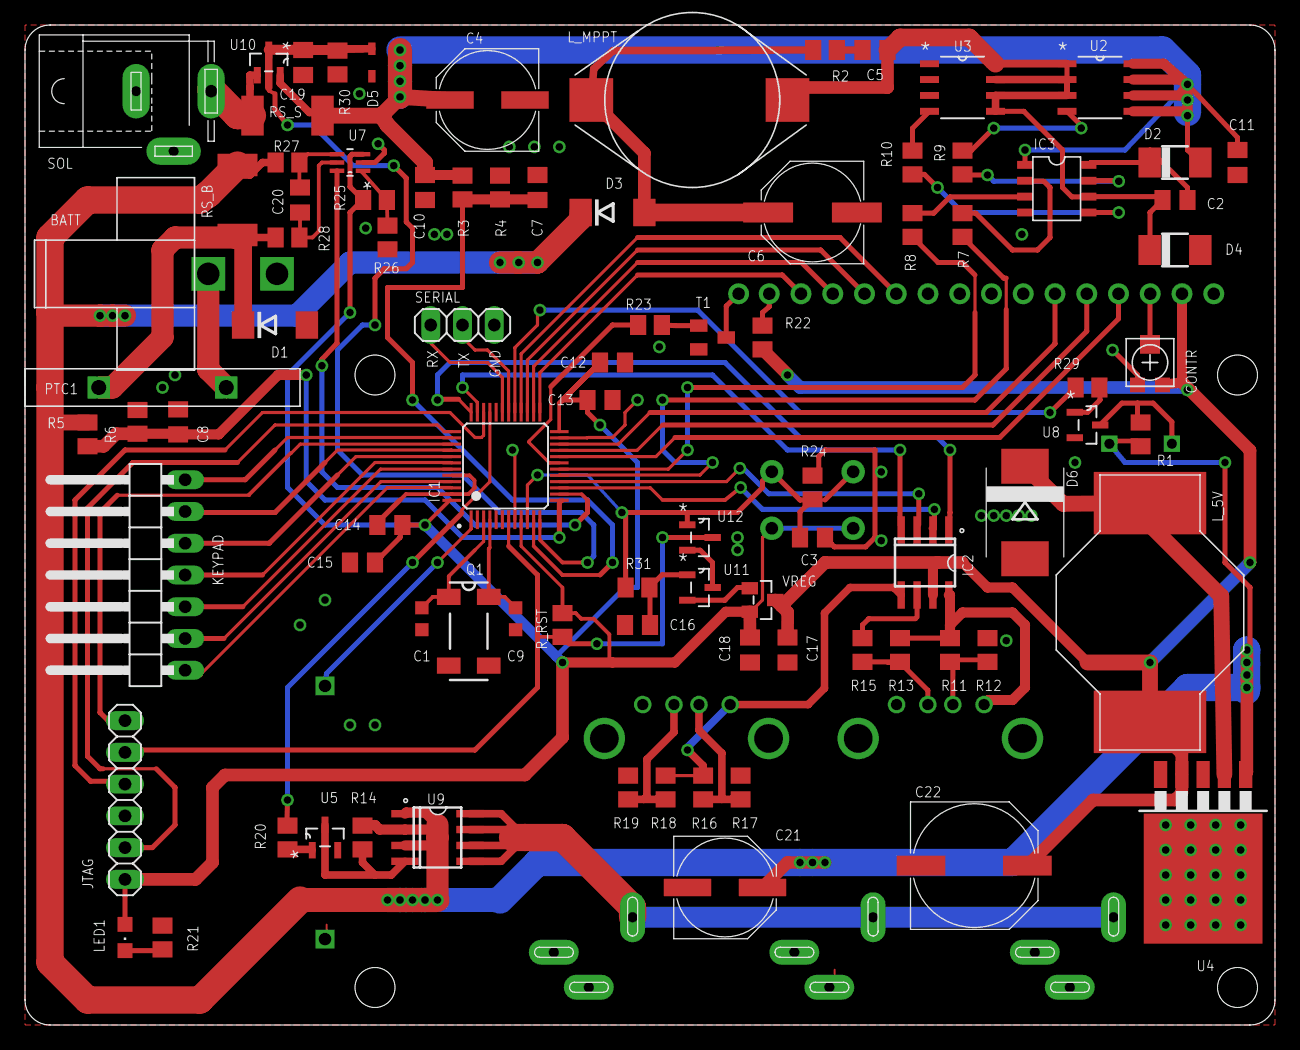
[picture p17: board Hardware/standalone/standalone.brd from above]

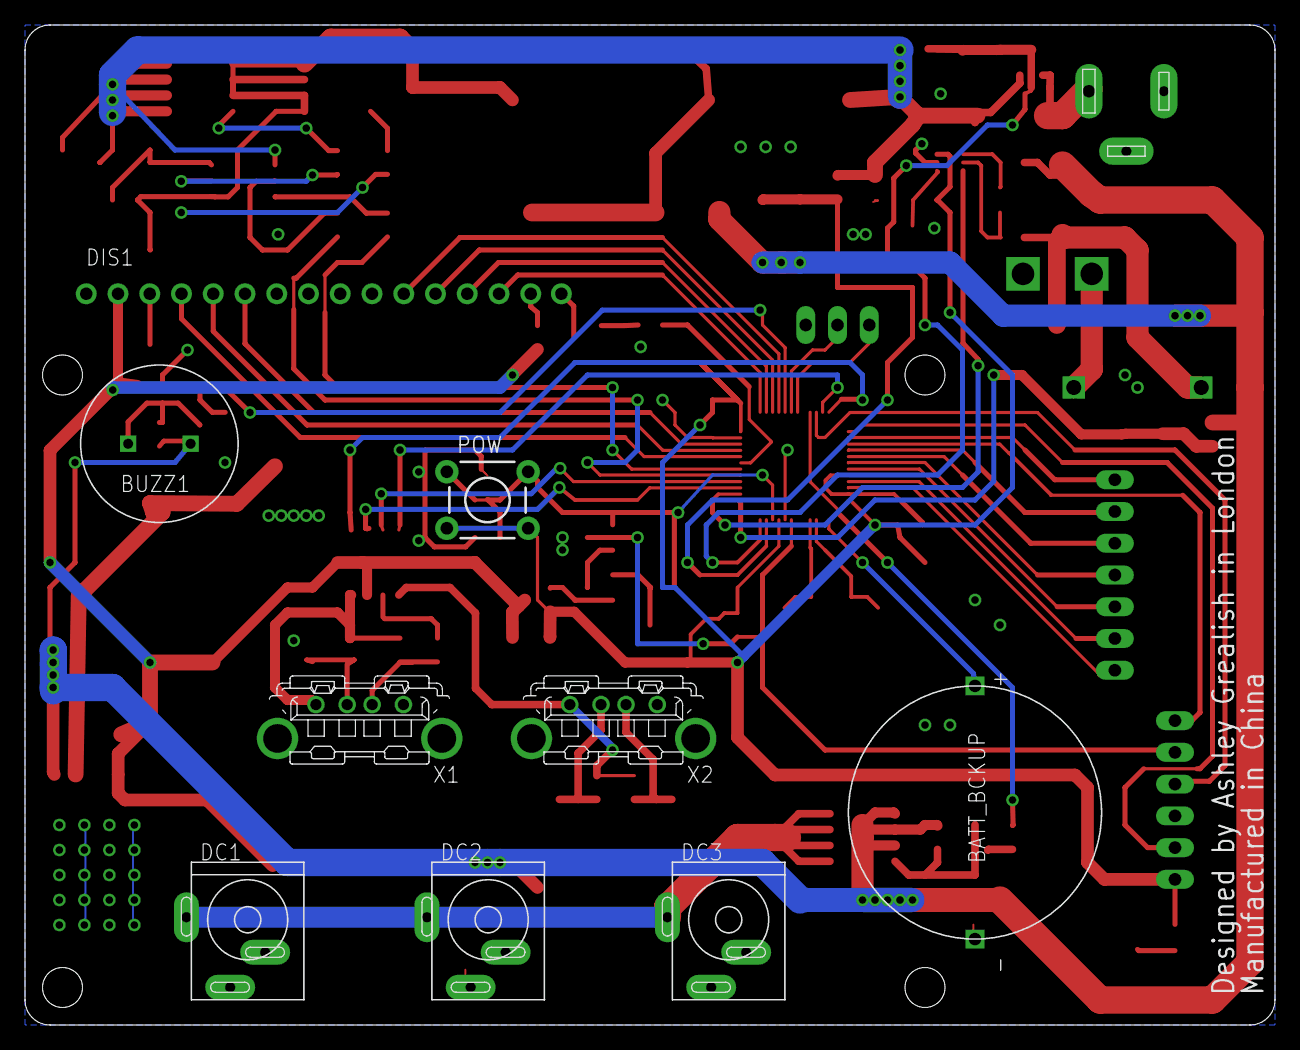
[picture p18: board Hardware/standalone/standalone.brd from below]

Board: 2 copper layers, 100.0 x 80.0 mm, 98 parts (10 on the bottom side), 77 nets.

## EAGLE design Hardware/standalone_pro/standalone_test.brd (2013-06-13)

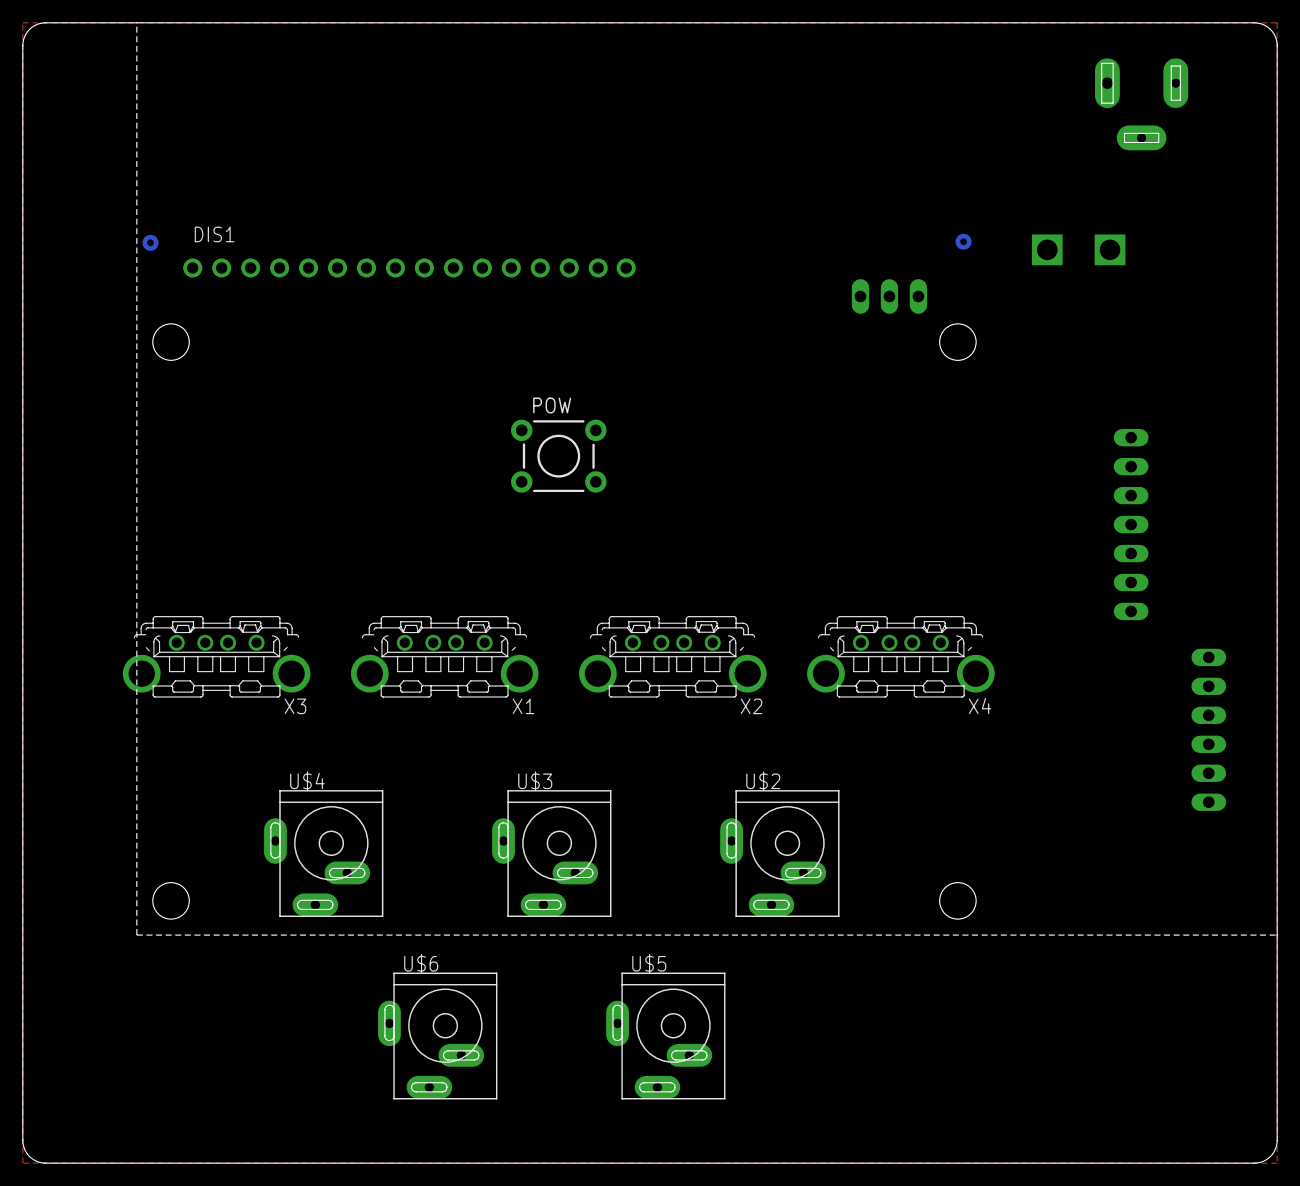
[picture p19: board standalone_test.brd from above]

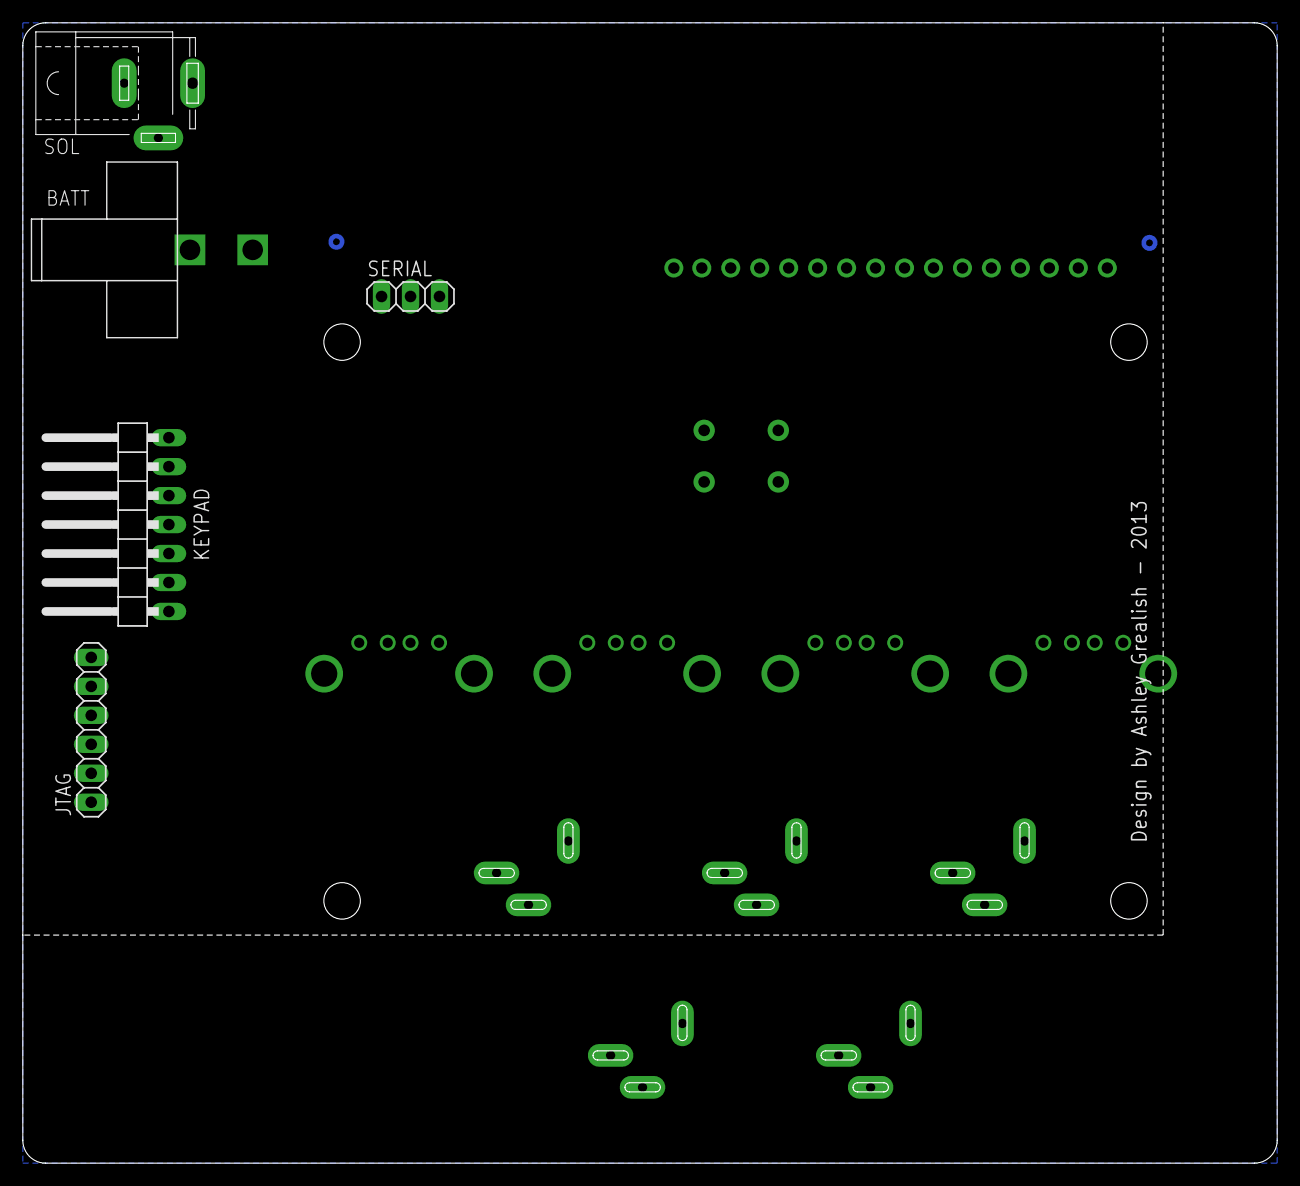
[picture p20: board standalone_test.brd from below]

Board: 2 copper layers, 110.0 x 100.0 mm, 17 parts (5 on the bottom side), 5 nets, no tracks yet.

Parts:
BATT: CON_MOLEX_39_29_1028; MOLEX_39_29_1028
DIS1: LCD_16X2_R2
JTAG: 1X06
KEYPAD: 1X07/90
POW: TACTILE-PTH
SERIAL: 1X03
SOL: SPC4077
U$1: EQUINOX_LOGO_LARGE
U$2, U$3, U$4, U$5, U$6: KYCON_KLDVX-0202; KYCON_KLVDX_2020_B
X1, X2, X3, X4: KUSBVX

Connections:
GND: BATT.P$2, SERIAL.3, SOL.1, SOL.2, U$4.2, U$5.2, U$5.3, U$6.2, U$6.3, X1.4, X1.M1, X1.M2, X2.4, X2.M1, X2.M2, X3.4, X3.M1, X3.M2, X4.4, X4.M1, X4.M2
unnamed: DIS1.7, DIS1.8, DIS1.9, DIS1.10
unnamed: U$3.2, U$3.3
S$6: POW.3, POW.4
S$7: U$2.2, U$2.3

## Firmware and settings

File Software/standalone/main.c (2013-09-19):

/**
  ******************************************************************************
  * @file    standalone/main.c 
  * @author  Ashley Grealish
  * @version V1.0.0
  * @date    31-Jan-2013
  * @brief   Main program body
  ******************************************************************************
  * @attention
  ******************************************************************************
	*
	* Enviroment Set Up:
	* Follow 
	programming instructions here to upgrade STM32F0 Board Firmware
	* http://dduino.blogspot.co.uk/2012/06/stm32f0-discovery-board.html
	* This improves stability and fixes the many crashes.
  */
	

/* Includes ------------------------------------------------------------------*/
#include "standalone_config.h"

#include "serial.h"
#include "adc.h"
#include "pwm.h"
#include "perturb_and_observe.h"
#include "interrupted_charging.h"
#include "ui.h"
#include "payment_control.h"


/* Private variables ---------------------------------------------------------*/

/* Private function prototypes -----------------------------------------------*/


__task void init (void) 
{	
	//Maximum of four running tasks, so can only launch three tasks here, any more will be ignored.

	//Start the interrupted charging algoritm
	TRACE_DEBUG("Starting Interrupted Charging Task\n");
	interrupted_charging_t = os_tsk_create_user ( interrupted_charging, 0, &interrupted_charging_stk , sizeof(interrupted_charging_stk) );
	if (!interrupted_charging_t)
		TRACE_ERROR("Interrupted Charging Task Failed to launch\n");
	
	TRACE_DEBUG("Starting UI task\n");
	ui_t = os_tsk_create_user (ui, 2, &ui_stk, sizeof(ui_stk) );
	if (!ui_t)
		TRACE_ERROR("UI Task Failed to launch\n");
	
	TRACE_DEBUG("Starting Payment Control task\n");
	payment_control_t = os_tsk_create_user (payment_control, 1, &payment_control_stk, sizeof(payment_control_stk) );
	if (!payment_control_t)
		TRACE_ERROR("Payment Control Task Failed to launch\n");

// 	//Can be used to test ADC readings
// 	TRACE_DEBUG("Starting adc_in task \n");
// 	adc_test_t = os_tsk_create( adc_test, 0);
// 	if (!adc_test_t)
// 		TRACE_ERROR("ADC Task Failed to launch \n");
			
	os_tsk_delete_self ();
}


/**
  * @brief  Main program.
  * @param  None
  * @retval None
  */
int main(void)
{

	Serial.begin(115200); //Open com on uart1 0-1 pins
	/*
	TRACE_ERROR_WP("\n");
	TRACE_ERROR_WP("\n");
	TRACE_ERROR_WP("e.quinox izuba.box Serial Interface\n");
	TRACE_ERROR_WP("Author: %s\n", CODE_AUTHOR );
	TRACE_ERROR_WP("Contact: %s\n", CODE_AUTHOR_EMAIL );
	TRACE_ERROR_WP("Compiled: %s %s\n", __DATE__, __TIME__ );
	TRACE_ERROR_WP("\n");
	TRACE_ERROR_WP("\n");
  */
	os_sys_init(init); 
	
	while(1);
	
}


#ifdef  USE_FULL_ASSERT

/**
  * @brief  Reports the name of the source file and the source line number
  *         where the assert_param error has occurred.
  * @param  file: pointer to the source file name
  * @param  line: assert_param error line source number
  * @retval None
  */
void assert_failed(uint8_t* file, uint32_t line)
{
  /* User can add his own implementation to report the file name and line number,
     ex: printf("Wrong parameters value: file %s on line %d\r\n", file, line) */
	//
	//TRACE_FATAL("Wrong parameters value: file %s on line %d\n", file, line);

  /* Infinite loop */
  while (1)
  {
  }
}
#endif

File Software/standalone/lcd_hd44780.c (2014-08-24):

// Includes
#include "lcd_hd44780.h"


//Data Pin Definitions
	//PORT B
#define LCD_D4	GPIO_Pin_15
#define LCD_D5	GPIO_Pin_14
#define LCD_D6	GPIO_Pin_13
#define LCD_D7	GPIO_Pin_12

//Control Pin Definitions
	//PORT 
#define LCD_RS	GPIO_Pin_2
// \/ THIS PIN IS NEVER USED!!! \/
#define LCD_RW	GPIO_Pin_10
#define LCD_E		GPIO_Pin_11

#define LCD_BK_EN GPIO_Pin_1
#define LCD_PWR		GPIO_Pin_11

//Macro Definitions
#define		LCD_DISP_ON			0x0c
#define		LCD_DISP_OFF		0x08
#define		LCD_CLR					0x01
#define		LCD_HOME				0x02

#define INPUT	0
#define OUTPUT 1

//Function Prototypes
void delay_us (int);
void delay_ms (int);
//void delay100u (int);
void cycle_e (void);
void lcd_send_4_bits (uint8_t);
void lcd_set_custom_chars (void);

OS_ID bk_tmr = NULL;


void set_data_io ( int io )
{
	GPIO_InitTypeDef GPIO_InitStructure;
	
	GPIO_InitStructure.GPIO_Pin = LCD_D4 | LCD_D5 | LCD_D6 | LCD_D7;
	if (io == INPUT)
		GPIO_InitStructure.GPIO_Mode = GPIO_Mode_IN;
	else
		GPIO_InitStructure.GPIO_Mode = GPIO_Mode_OUT;
  GPIO_InitStructure.GPIO_OType = GPIO_OType_PP;
  GPIO_InitStructure.GPIO_Speed = GPIO_Speed_50MHz;
  GPIO_InitStructure.GPIO_PuPd = GPIO_PuPd_NOPULL;	
	GPIO_Init(GPIOB, &GPIO_InitStructure);
	
}

uint8_t read_data_inputs (void) {
	uint8_t temp = 0;
	
	temp = GPIO_ReadOutputDataBit(GPIOB, LCD_D4);
	
	temp |= GPIO_ReadOutputDataBit(GPIOB, LCD_D5) < 1;
	temp |= GPIO_ReadOutputDataBit(GPIOB, LCD_D6) < 2;
	temp |= GPIO_ReadOutputDataBit(GPIOB, LCD_D7) < 3;
	
	return temp;
}

void lcd_wait()
{
	//This function waits till lcd is BUSY

	uint8_t busy, temp;
	uint8_t status=0x00;
	
	//Change Port to input type because we are reading data
	//LCD_DATA_TRIS|=0x0F;
	set_data_io(INPUT);

	//change LCD mode
	//SET_RW();		//Read mode
	GPIO_SetBits(GPIOB, LCD_RW);
		
	//CLEAR_RS();		//Read status
	GPIO_ResetBits(GPIOB, LCD_RS);

	//Let the RW/RS lines stabilize
	delay_us(0.5);		//tAS

	
	do
	{

		//SET_E();
		GPIO_SetBits(GPIOB, LCD_E);
		

		//Wait tDA for data to become available
		delay_us(0.5);

		status = read_data_inputs();
		status = status<<4;

		delay_us(0.5);

		//Pull E low
		//CLEAR_E();
		GPIO_ResetBits(GPIOB, LCD_E);
		
		delay_us(1);	//tEL

		//SET_E();
		GPIO_SetBits(GPIOB, LCD_E);
		
		delay_us(0.5);

		temp = read_data_inputs();
		temp &= 0x0F;

		status = status | temp;

		busy = status & 0x80;

		delay_us(0.5);
		
		//CLEAR_E();
		GPIO_ResetBits(GPIOB, LCD_E);
		
		delay_us(1);	//tEL
		
	} while (busy);

	//write mode
	//CLEAR_RW();
	GPIO_ResetBits(GPIOB, LCD_RW);
	
	//Change Port to output
	//LCD_DATA_TRIS&=0xF0;
	set_data_io(OUTPUT);

}


void lcd_backlight(char en)
{
	if (en)
	{
		GPIO_SetBits(GPIOB, LCD_BK_EN );
		
		//Stop old timer
		if (bk_tmr != NULL)
			os_tmr_kill(bk_tmr);
		
		//Restart timer
		bk_tmr = os_tmr_create (BK_TIMEOUT_S*100, 1);
		if (bk_tmr == NULL)
			TRACE_ERROR("Failed to create backlight timer \n");
		
	}
	else
	{
		//Stop old timer
		os_tmr_kill(bk_tmr);
		
		GPIO_ResetBits(GPIOB, LCD_BK_EN );
	}
}


void lcd_bk_tmr_expire(void)
{
	GPIO_ResetBits(GPIOB, LCD_BK_EN );
}

void lcd_power(char en)
{

	lcd_backlight(en);
	if (en)
	{
		lcd_send_cmd(LCD_DISP_ON);
	}
	else
	{
		//Turn off the display in software
		lcd_send_cmd(LCD_DISP_OFF);
	}
}

void lcd_write_int(const int val)
{
	char str[16];
	
	if ( snprintf( &str[0], 16, "%d", val ) > 16 )
			TRACE_WARNING( "String too long \n");
	
	lcd_write_string(str);
}

void lcd_write_string(const char *msg)
{
	while(*msg!='\0')
	{
		lcd_putc(*msg);
		msg++;
	}
}

void lcd_goto_XY(uint8_t x, uint8_t y)
{
	//Default line 0, pos 0 address
	uint8_t addr = 0x80;
	
	if ( y == 1 )
		addr = 0xC0;
	
	addr += x;	
  lcd_send_cmd(addr); 
}

void delay_ms (volatile int ms) {
	while (ms--)
	{
		delay_us(1000);
	}
}

void delay_us (volatile int us) {
	// delays for 1 microseconds * dly
  // at default clock speed (40MHz)
  volatile int inner;
  while(us--) 
  {
    inner=13;
    while(inner--);
  }
}

void cycle_e (void)
{
	tsk_lock();
  GPIO_SetBits(GPIOB, LCD_E);
  delay_us(1);
  GPIO_ResetBits(GPIOB, LCD_E);
  delay_us(1);
	tsk_unlock();
	lcd_wait();
}

void lcd_init (void) 
{
	//Variables
	GPIO_InitTypeDef GPIO_InitStructure;
		
	//Turn on GPIOB Clock for port B
	RCC_AHBPeriphClockCmd( RCC_AHBPeriph_GPIOB, ENABLE);
	
	//Configure Pins
	GPIO_StructInit(&GPIO_InitStructure);
	
	GPIO_InitStructure.GPIO_Pin = LCD_D4 | LCD_D5 | LCD_D6 | LCD_D7 | LCD_RS | LCD_RW | LCD_E | LCD_BK_EN ;
	GPIO_InitStructure.GPIO_Mode = GPIO_Mode_OUT;
  GPIO_InitStructure.GPIO_OType = GPIO_OType_PP;
  GPIO_InitStructure.GPIO_Speed = GPIO_Speed_50MHz;
  GPIO_InitStructure.GPIO_PuPd = GPIO_PuPd_NOPULL;	
	GPIO_Init(GPIOB, &GPIO_InitStructure);
	
	GPIO_StructInit(&GPIO_InitStructure);
	
	GPIO_InitStructure.GPIO_Pin = LCD_PWR;
	GPIO_InitStructure.GPIO_Mode = GPIO_Mode_OUT;
  GPIO_InitStructure.GPIO_OType = GPIO_OType_PP;
  GPIO_InitStructure.GPIO_Speed = GPIO_Speed_2MHz;
  GPIO_InitStructure.GPIO_PuPd = GPIO_PuPd_NOPULL;	
	GPIO_Init(GPIOA, &GPIO_InitStructure);
	
	
	//If reset due to user holding power button for >10s
// 	if ( RCC_GetFlagStatus(RCC_FLAG_PINRST) == SET ) {	
// 		TRACE_INFO("Hardware Reset was detected\n");
// 		
// 		//Clear Flag
// 		RCC_ClearFlag();
// 		
// 		lcd_power(1);
// 		lcd_clear();		
// 	}
// 	else
// 	{
		//LCD Not Inited so Init it
		
		GPIO_ResetBits(GPIOB, (LCD_E | LCD_RS | LCD_RW ) );
		GPIO_ResetBits(GPIOB, (LCD_D4 | LCD_D5 | LCD_D6 | LCD_D7 | LCD_BK_EN) );

		GPIO_SetBits(GPIOA, LCD_PWR);	
		
		tsk_lock();
		delay_ms(100);
		tsk_unlock();
		
		lcd_send_cmd(0x30);
		delay_ms(5);
		lcd_send_cmd(0x30);
		delay_us(100);
		lcd_send_cmd(0x30);
		delay_us(100);
			
		GPIO_SetBits(GPIOB, LCD_D5);
		cycle_e();
		//lcd_wait();
		
		lcd_send_cmd(LCD_DISP_ON);
		lcd_send_cmd( 0x28 );
		
		lcd_set_custom_chars();
		
		lcd_clear();		
// 	}
}

void lcd_send_4_bits (uint8_t c)
{
	//Bit messy but required if any
	//combinations of data pins can be used
	
	if ( (c >> 0) & 0x01 )
		GPIO_SetBits(GPIOB, LCD_D4 );
	else
		GPIO_ResetBits(GPIOB, LCD_D4 );
	
	if ( (c >> 1) & 0x01 )
		GPIO_SetBits(GPIOB, LCD_D5 );
	else
		GPIO_ResetBits(GPIOB, LCD_D5 );
	
	if ( (c >> 2) & 0x01 )
		GPIO_SetBits(GPIOB, LCD_D6 );
	else
		GPIO_ResetBits(GPIOB, LCD_D6 );
	
	if ( (c >> 3) & 0x01 )
		GPIO_SetBits(GPIOB, LCD_D7 );
	else
		GPIO_ResetBits(GPIOB, LCD_D7 );
}


void lcd_send_cmd (uint8_t c)
{
	//Send Upper Bits
	lcd_send_4_bits(c>>4);
	GPIO_ResetBits(GPIOB, LCD_RS);
	cycle_e();
	
	//Send Lower Bits
	lcd_send_4_bits(c);	
	GPIO_ResetBits(GPIOB, LCD_RS);
	cycle_e();
	//lcd_wait();
}

void lcd_clear (void)
{
	lcd_send_cmd(LCD_CLR);
	os_dly_wait(1);
}

void lcd_putc (char c)
{
	//Send Upper Bits
	lcd_send_4_bits(c>>4);
	GPIO_SetBits(GPIOB, LCD_RS);
	cycle_e();
	
	//Send Lower Bits
	lcd_send_4_bits(c);	
	GPIO_SetBits(GPIOB, LCD_RS);
	cycle_e();
}

__inline void lcd_send_data (uint8_t data)
{
	lcd_putc(data);
}
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

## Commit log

2013-03-11 Added lates MPPT Tracking PCB design
    Also cleaned hardware folder, removing non-working current sense
    designs.
    [connectors.brd, current_sense.brd, current_sense.sch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]
2013-03-26 Some updates to MPPT hardware and software
    The design now can charge lead acid batteries but no high/low voltage
    cut-out is enabled.
    [Processor_test.sch, bom.xls, mppt.brd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]
2013-03-26 First Version of Standalone Connectors Layout
    Prototype Faceplate is being designed based on this layout.
    [connectors.brd, connectors.sch]
2013-03-28 Fist Full Standalone V2 Proo
    [Processor_test.sch, standalone.brd, standalone.sch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]
2013-03-28 Added item to hardware todo list
    [standalone.sch]
2013-03-28 Add RTC and LCD Drivers
    These are both untested as no access to hardware currently
2013-03-29 ADC now read Continuously with DMA Access
    Should reduce CPU load fix the ADC not reading error.
    May need to add low pass filtering with 20kHz cut off to remove
    switching noise. Simply averaging many reads of ADC will no longer work.
    [adc.c]
2013-03-29 ADC Continuous Mode Tested and Working
    Missed out call to the init function. Now fixed and working.
    [adc.c, adc.h, main.c]
2013-03-31 Fixed RTC Enable Code
    Correct Peripheral Clock was not being enabled
    [main.c]
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2013-04-01 Added two extra ADC Channels to read from
    get_adc_voltage can now read current and voltage from battery or solar
    panel.
2013-04-01 Interrupted Charging Algorithm Ready for Testing
    Not yet tested due to lack of Sunlight, thanks UK.
2013-04-20 Changed Software Target Device to STM32F050C6
    This also required making the stack size smaller to fit within the 4k
    RAM. If one task needs more stack then this can be defined with
    os_tsk_create_user().
2013-04-20 Some Hardware Fixes
    Fixed the Battery Connector.
    Added more items to ToDo list
    [standalone.brd, standalone.sch]
2013-04-20 Added Latest Bill of Materials
    [bom.csv, bom.xlsx]
2013-04-21 Cleaned Library and Complete some ToDo list
    Added power LED and changed MPPT reverse current diode
    [standalone.brd, standalone.sch]
2013-04-21 Moved Serial output to USART1
    Also added some extra error checking and changed Compiler Options to
    reduce code size. Now performs two step compilation to optimise across
    modules. Also makes use of MicroLib, space optimised C libraries.
    [main.c, serial.h]
2013-04-23 Many PCB Improvements
    Tidied up Silkscreen.
    Changed some through hole components to surface mount.
    Changed the 15V regulator for 5V as originally intended.
    Checked power rating of converters. Need to update 5V out to 3A.
    On PCB, tidied up the 12V track and thickened so that it can carry
    larger current.
    [standalone.brd, standalone.sch]
2013-05-14 Increase 5V Output to 3A max
    Switched SMPS Controller, Inductor and Capacitor.
    [standalone.brd, standalone.sch]
2013-05-17 Moved Mounting Holes and Removed DC Jack Holes
    [standalone.brd, standalone.sch, standalone_not_autorouted.brd]
2013-05-20 Moved PWM Output to Correct Pin
    Code now matches hardware
    [main.c, pwm.c]
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2013-05-24 lcd_hd44870 fixed and made more usable
    lcd_hd44780 library updates and tested.
    Extra functions such as write string/int and gotos added
    [lcd_hd44780.c]
2013-05-25 ADC Channels Corrected for STM32F050C6
    [adc.c, adc.h]
2013-05-25 Enabled Pull-Up Resistors on USB Error Flag Pins
    [main.c]
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2013-05-27 USB Error Protection Implemented with Interrupts
    Interrupt on USB_FLG falling edge. Causes USB port that caused the error
    to be disabled.
    [main.c]
2013-05-27 Fixed Pin Definitions for Serial Port
    Serial Port Now Working
    [main.c, serial.h]
2013-05-27 Move Charge Controller Enable Pin Init
    Now init'ed at same time as PWM Output Pin
2013-05-28 Improved LCD Init. Fixes unreliability problems
    [lcd_hd44780.c]
2013-05-28 Major PCB Re-arrangements and Fixes
    [standalone.brd, standalone.sch]
2013-05-29 PCB 100% Routed
    [standalone.brd, standalone.sch]
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2013-05-29 PCB Fixes
    LCD Power Switch Added.
    [standalone.brd, standalone.sch]
2013-05-29 PCB Rev2 Complete. Ready for manufacture
    [standalone.GBL, standalone.GBO, standalone.GBP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]
2013-05-29 Cleanup of un-needed files
    [bom.xls, connectors.brd, connectors.sch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]
2013-05-29 Increased via size to reduce Manufacturing Costs.
    10 euro reducing in unit cost from eurocircuits
    [standalone.brd]
2013-05-30 First izuba.box pro commit
    Mostly just a test for the connectors layout
    [standalone.brd, standalone.sch, standalone_test.brd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]
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2013-05-30 First Test of Keypad Code
    Working but needs to be implemented with interrupts and de-bouncing
    Hardware pull up resistors no longer required. Internal uC pull ups are
    used.
    [standalone.sch]
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2013-06-02 Fixed pwm_out test task
    [pwm.c]
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2013-06-02 Added Constant Current Control to P&O Algorithm
    Allows the passing of a maximum battery current which will be allowed
    during MPPT.
2013-06-02 Fixed keypad_get_key()
    Pins were not being reset to 0 before exit.
    [standalone.brd]
2013-06-02 Added better keypad de-bouncing
    Still needs some work to make more responsive.
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2013-06-05 Added LVDC and Fixed the exiting of Night Mode
    [interrupted_charging.c, main.c, perturb_and_observe.c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]
2013-06-05 Removed Keypad Pullups and Fixed MPPT out tracks
    [standalone.brd, standalone.sch]
2013-06-05 Fixed Pulsed Charging Code
    [interrupted_charging.c]
2013-06-05 Fixed Power Switch Interrupt Handling
    [ui.c]
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2013-06-06 Fixed ADC Task and some ADC Calibration Factors
    [adc.c, adc.h]
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2013-06-06 Fixed Stack sizes for Tasks
    Can now run 4 tasks at the same time.
    Stack size is normally set by the creation of the task.
    Default stack size is now much smaller.
    [adc.c, adc.h, interrupted_charging.c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]
2013-06-06 Use DMA to fill ADC Averaging Arrays
    Reduces the overhead of using interrupts to copy the data between memory
    space.
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2013-06-07 Updated BOM
    [bom.csv, bom.xlsx]
2013-06-07 Added Payment Control Task and Fixed CC Logging
    [interrupted_charging.c, main.c, perturb_and_observe.c]
2013-06-08 Updated MPPT Inductor and added comments
    [standalone.brd, standalone.sch]
2013-06-08 BOM Updated
    [bom.xlsx]
2013-06-08 Move RTC Code to task and changed RTC Clock
    RTC Clock now uses the external 32.768kHz Xtal on the board
2013-06-13 Hardware fixes
    [standalone.brd, standalone.sch]
2013-06-13 BOM Updates
    [bom.xlsx]
2013-06-13 Standalone pro physical layout finalised
    [standalone.sch, standalone_test.brd]
2013-06-13 Moved drill holes to correct position
    [bom.xlsx, standalone.brd, standalone.sch]
2013-06-14 Latest V2.4 PCB design (Sent to EuroCircuits)
    [standalone.GBL, standalone.GBO, standalone.GBP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]
2013-06-15 Clean up of Hardware folder
    [standalone.GBL, standalone.GBO, standalone.GBP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]
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2013-06-22 Pro Standalone board updated
    [standalone.brd, standalone.sch]
2013-06-22 Added Relay to Standalone Pro
    [standalone.brd, standalone.sch]
2013-07-05 Connections added (with corrected faults)
    [standalone.brd, standalone.sch]
2013-07-05 More corrections on relay
2013-07-05 Fixed Phantom Key typing bug. Clean up of buzzer
    Was caused by not having the KEY_NONE error check
    [buzzer.c, ui.c]
2013-07-05 Decreased Serial Receive Buffer Size
    Large buffer not needed as code never receives data with current code.
2013-07-05 RTC temp switched to Internal RC Oscillator
    When hardware fixed switch back to External Oscillator but with a
    internal Oscillator backup for failure of external XTAL.
    [interrupted_charging.c]
2013-07-05 Parallel Resistor added to buzzer circuit.
    [standalone.brd, standalone.sch]
2013-07-06 Components on correct side and gnd ripped up
    [standalone.brd, standalone.sch]
2013-07-06 Drc; overlap errors corrected
    [standalone.brd]
2013-07-06 Gnd connected
    [standalone.brd]
2013-07-06 New overlap fixed
    [standalone.brd]
2013-07-10 Changed RTC XTAL Hardware
    Both Home and Pro boards have working XTAL. OC_FARNELL attributes give
    correct part numbers.
    [standalone.brd, standalone.sch]
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2013-07-17 izuba.box home production data added
    This production data will be used to obtain a quote for assembly from
    quick-tech.
    [bom.xlsx, home_bom.xlsx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]
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2013-07-21 Fixed update of remaining days on LCD
    [ui.c]
2013-07-22 Pro Unit Hardware design completed
    [standalone.brd, standalone.sch]
2013-07-22 Small Changes to Pro Board and Gerbers Made
    [standalone.GBL, standalone.GBO, standalone.GBP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]
2013-07-22 Updated Home Bill of Materials
    Part numbers for all items now up-to-date and Quick-Tech catalogue parts
    have been used.
    [home_bom.xlsx]
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2013-07-27 More details added to BOM
    [home_bom.xlsx]
2013-07-28 BOM updated with Prices
    [home_bom.xlsx]
2013-08-03 Pro hardware ready for first prototype
    [quick-teck parcel contents.xlsx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]
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2013-08-03 Current compensation on CC re-implemented
    This is used to adjust the upper voltage threshold for charging and also
    used to calculate SOC for display on the LCD.
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2013-08-25 Add Pro BOM
    [bom.csv]
2013-08-27 Updates Pro MPPT Inductor Part #
    [bom.csv, standalone.brd, standalone.sch]
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2013-09-19 Fixed the FULL UNLOCK CODE
    - When the box is fully unlocked, it will give the user 9999 days (27
    years) and will display unlocked on the LCD
    - The implementation of this required more memory and therefore I
    removed the TRACE_ERROR function call in interrupted charging.
    [interrupted_charging.c, lcd_hd44780.c, main.c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]
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2013-09-19 Fixed an Issue with the last unlock code
    The Unlock code would re-appear after the unlock time expires and
    sometimes would put the box in an unknown state. This has been fixed in
    this commit by simply re-initializing the entry_code, display_str and
    digit_count variables to 0 after a valid code has been entered.
    [ui.c]
2013-09-22 Possible LCD Fix
    Started Implementing better LCD Driver which reads data from LCD but
    Init function does not make use of this yet
    Changed the Init Function slightly, this seems to fix the corruption of
    Reset Issue. This issue appears to happed when calling lcd_init() twice
    without removing power to the PCB.
    [lcd_hd44780.c]
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2013-09-23 More LCD Tweaks
    Fixes some issues introduced in last commit
    [lcd_hd44780.c]
2013-09-23 LCD Driver Using Polls LCD for timing
    LCD Driver uses polling of the LCD rather than hard coded timings. This
    was meant to fix the corruption issues but does not appear too.
    [lcd_hd44780.c]
2013-09-23 Better USB Error Handling
    Written by Kishan.
    [ui.c]
2014-08-24 Modified LCD initialisation to avoid random characters
    Additional 'Function Set' commands added to the LCD initialisation
    routine. This avoids the LCD defaulting to 8-bit mode rather than 4-bit
    mode if the microcontroller is reset without also power cycling the LCD.
    Entering 8-bit mode results in incorrect characters being displayed due
    to a different interpretation of data from the data pins, and half of
    the data pins required for 8-bit mode not being connected.
    [lcd_hd44780.c]
2014-09-06 Fixed LVDC infinite loop
    Resolved problem where the LVDC event flag (UI_LVDC) was used instead of
    the LVDC user interface state (STATE_LVDC). This previously resulted in
    an infinite loop when the system entered this state. Also set the LCD to
    be cleared before being turned on, to avoid the previous data being
    displayed.
    [ui.c]
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
